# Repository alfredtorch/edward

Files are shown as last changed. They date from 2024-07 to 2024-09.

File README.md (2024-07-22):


Edward is an innovative solution that synergizes citizen science with urban farming, utilizing an advanced aquaponic system to address environmental challenges. Edward aims to produce sustainable food sources while fostering community involvement and contributing to a healthier, more sustainable urban environment.

Designed as an expansive urban farming laboratory, Edward initially focuses on aquaponics. This highly efficient farming method is capable of producing local food with minimal resource impact and effort. By transforming existing water bodies, such as ponds or basins, into productive food sources, Edward epitomizes the principles of the circular economy.

Key Features
- Smart Garden Community: Build your self-sufficient technology platform and transform public spaces into urban farming areas.
- Citizen Science: Share information and engage in community-driven research.
- Open Source: Driven by the community, promoting collaboration and innovation.
- Modular Design: Based on the principles of the circular economy, allowing adaptability and scalability.
<p align="center">

</p>

> ## Software Development Needed
> Please visit the [Software Specification Sheet](SoftwareSpecificationSheetM2.md) if you would like to collaborate and help to develop Edward.
> ## On-Going Documentation
> Different sections in this repository needs to verified. Please feel free to submit corrections, if you would like to collaborate and help to develop Edward.

# Growing Lab & Sharing Knowledge
Edward fosters continuous improvement through community involvement at multiple levels. Individuals manage local stations, benefit from fresh food, and participate in testing new biological scenarios. This approach enriches community knowledge and enhances the numerical model.

<p align="center">

</p>

The Sustainable Food Cycle and Optimization Biological Cycle are central to Edward's innovative approach. The Sustainable Food Cycle focuses on creating a cradle-to-cradle system where organic waste is transformed into bio converters and natural bio cycles, producing organic food for fish and yielding fresh vegetables. This cycle epitomizes resource efficiency and sustainability. Meanwhile, the Optimization Biological Cycle leverages citizen science and advanced technologies like machine learning and autonomous control to refine and enhance farming practices. Through community-driven research, scenario experimentation, and gamification, this cycle ensures continuous improvement and optimization of the entire system.

<p align="center">

</p>

## Sharing Knowledge
For individuals, Edward offers a novel way to connect with nature and their community. Members assume shared responsibility for their plants and fish, gaining knowledge and forming new connections, both digitally and in person. This hands-on experience not only yields healthy food but also underlines a Return on Research (RoR) approach, valuing the knowledge gained from community-led research and innovation.

Key Features
* Citizen-Operated Stations: Gather observations for new biological scenarios like light conditions or tidal cycles.
* Mobile App Support: Easy sharing of observations with scientists, encouraging dynamic information exchange.
* Participative and Gamified Approach: Encourages dialogue, sharing through text and images, and collective data contribution.
* AI-Driven Insights: Data from multiple stations feed into AI models for valuable insights into small-scale and industrial agricultural practices, such as pisciculture.

## Research Project 1 : Water Cooled LEDs


Improve the maintenance cost and efficiency with water-cooled LEDs for grow lights. This study focuses on the efficient thermal management of the grow light. Optimal cooling will provide long-term stable light characteristics and increase lifespan. Additionally, the possible waste heat can be used to heat the fish tank.

## Phases
1. **Design Possibilities:** Explore various design possibilities such as heat sinks, LED holders, and more.
2. **Check Safety Concerns:** Address safety concerns including risks of electrocution, fire hazards, and appropriate light levels.
3. **Regulate Water Pump and Light Intensity:** Control the water pump and adjust light intensity based on a state machine and scheduling.
4. **Measure Light Quality:** Assess light quality by measuring energy, wavelengths, and consumption over time.

## Development Project 1 : Move away from Home Assistant


The current prototype system is powered by Home Assistant with ESPHome running on a local Raspberry Pi. This setup was great for quickly prototyping a proof of concept. However, the main challenges faced by the current system are:
- It is not a standalone system (requires both Raspberry Pi and Station Controller).
- There is no option for easy remote monitoring of the system (NAT, DNS, Public IP).
- Missing control options (regular self-calibration, failsafe mode).

<p align="center>
  >
</p>

# Files & Folders
The project is currently mainly organised in this respository.
All shared by Licence... 
## [Hardware](Hardware.md)
## [Hardware PCB Repo](/Hardware/)
## [Components](Components.md)
## [Software YAML Repo](/Software/)
## [Software Devlopement Specification Sheet](SoftwareSpecificationSheetM2.md)
## [Discord Server](https://discord.gg/AFunXj2wjE)
## [HackADay.io Project](https://hackaday.io/project/197025-edwardfarm)

<a href="https://trackgit.com">
trackgit-views
</a>

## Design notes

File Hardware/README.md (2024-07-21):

| Filename | Notes |
| --- | --- |
FishTankControllerV2 | Control the Greenhouse & Fish Tank with safe DC motors |
GreenHouseControllerV2 | Control the Greenhouse & Fish Tank with with powerful AC motors |
IoTSSensorBoardV2 | Measure Heatsink Temperature LM75B or TMP1075 |
PowerMosfetGSVINRailV1 | Control 4 DC Load Module with GreenHouseControllerV2 |
PowerMosfetsSGVINRailV1 | Control 4 DC Load Modulel Module with GreenHouseControllerV2 |
Relay4ChannelBoard | Control 230V Relay 4Channel Module with GreenHouseControllerV2 |
SSR4ChannelBoard | Control 230V SSR 4Channel Module with GreenHouseControllerV2 |

<p align="center">

<br>
8 Channel Rebel - 8ChannelRebelSSR_v5
<br>

<br>
Helios - 8ChannelIoTLEDDriver
<br>

<br>
Green House - GreenHouseControllerV2
<br>

<br>
FishTankControllerV2
<br>

<br>
Relay4ChannelBoard - Control 230V Relay 4Channel Module with Green-House
<br>

<br>
SSR4ChannelBoard - Control 230V SSR 4Channel Module with Green-House
<br>

<br>
PowerMosfetGSVINRailV1
<br>

PowerMosfetSGVINRailV1
<br>
</p>

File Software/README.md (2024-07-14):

| File Name | YAML Content or Notes |
|---|---|
| Edward ESPHome.yaml | |
| Edward Helios ESPHome.yaml | Prototype Script for LED Grow Light (DC) with Temperature Monitoring |
| Edward Terra ESPHome.yaml | Prototype Script for Aquaponics with Tide and Light Scheduler (Optical Switch) |
| Edward User Interface.json | Node-Red Dashboard based on SVG UI Design |
| edward-grow-fuel.yam | Prototype Script for Aquaponics with Tide and Light Scheduler (Fuel Gauge) |

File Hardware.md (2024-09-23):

# Green House - Terra
The Green House - Terra board is designed to seamlessly integrate with your agricultural setup, enabling precise control over various actuators to enhance food production. This versatile board supports multiple devices and actuators, such as pumps and lights, making it ideal for diverse applications. While the fishtank version is highly accessible and beginner-friendly, the Green House - Terra platform offers unmatched versatility, capable of switching heavy loads running on mains power.

Features:
* ESP32-based
* Tasmota and Esphome Compatible
* Many PIN configuration possible (Solder Jumper)
* Many Vcc Configuration possible (Solder Jumper) with On Board Power Regulator 
* Open Source

<p align="center">

</p>

## Components
| Component | Description | Component | Description |
|---|---|---|---|
| ESP32 MCU | The core microcontroller unit powering the board | QWIIC I2C Connector | Simplifies the connection of sensors and modules |
| 4 Inputs for Water Level (Optical)  | Monitors water levels to ensure optimal conditions | Flow Meter (Hall Sensor) | Measures water flow rate accurately |
| Thermistor (Analog Temperature) | Provides precise temperature readings | 1-Wire Digital Temperature Sensor | Enables digital temperature monitoring |
| Sonar Sensor (Distance) | Measures distance using sonar technology | 4 Solid State Relays (5V Level) | Controls high-power devices with reliability and safety |
| Fan (Speed Control, Tachometer Sense) | Manages airflow with speed control and tachometer feedback | 2 Power Outputs (PWM-DC) | Drives power-hungry devices with PWM control |
| LED Strips (5V Data Line) | Controls LED lighting for various applications | Stepper Motor (28BYJ-48) | Drives stepper motors for precise mechanical control |
| 2 GPIO Pins | General-purpose input/output pins for custom applications | 2 Limit Switches | Detects end positions or limits in mechanical movements |
| Air Sensor (Humidity, CO2, Temperature, Pressure) | Monitors air quality and environmental conditions | Multiple VCC Buses | Provides flexible power distribution across multiple components |

## Pin-Out

| Pin  | Option 1 | Option 2 | Note |
|---|---|---|---|
| IO0  | Fan Signal Tacho | Stepper C | GPIO Selector Solder Jumper |
| IO2  | LED Status | | |
| IO4  | RGB | Solder Jumper | |
| IO5  | PIO3 | 5V Level - Mosfet Output | |
| IO12 | Button Board  | | |
| IO13 | PIO4 | RGB Pixel | 5V Level - Load Output |
| IO14 | Limit 1 | Servo 1 / Sonar Trigger | GPIO Selector Solder Jumper |
| IO15 | Servo 2 | Stepper D | GPIO Selector Solder Jumper |
| IO16 | Fan PWM | | |
| IO17 | 1-Wire | Dallas 1 Wire Sensor | |
| IO18 | Turbine Tacho | Flow Meter | |
| IO19 | PIO1 | | 3V3 Level |
| IO21 | SDA | | 3V3 Level |
| IO22 | SCL | | 3V3 Level |
| IO23 | PIO2 | | 5V Level |
| IO25 | Limit 1 | Stepper B | GPIO Selector Solder Jumper |
| IO26 | Turbine Therm | Water Temperature | |
| IO27 | Servo 1 / Sonar Trigger | Stepper A | GPIO Selector Solder Jumper |
| IO32 | Fan Tacho | Limit 2 | GPIO Selector Solder Jumper |
| IO33 | Limit 2 | Servo 2 | GPIO Selector Solder Jumper |
| IO34 | Water LEVEL 3 | | Optical or physical switch  |
| IO35 | Water LEVEL 2 | | Optical or physical switch  |
| IO36 | Water LEVEL 4 | Sonar Echo | Optical or physical switch  |
| IO39 | Water LEVEL 1 | | Optical or physical switch  |
| VIN1 | USB C, STEPPER, SERVO | | Max 30V, Input of DCDC 5V & 3V3 - direct 5V |
| VIN2 | RGB, VFAN, MOSFET | | Direct 5V |
| 5V | RGB, STEPPER, SERVO, MOSFET, VFAN | | |
| 3V3  | SERVO, MCU | | |

_Note: If a component (e.g., a Servo) operates at different voltage levels, it can be configured to use a single power source (e.g., 5V) through the use of solder jumpers._

<p align="center">

</p>

## ToDo
- [x] Use as Aquaponics Controll with ESPHOME (both fuelgauge and optical water)
- [ ] Test all configurations 

## Version

| Model | Notes |
|---|---|
| FishTankController V1  | Flow Meter Issue, 4 On-Board Load Power Switches (DC, Avoids 230V)  |
| GreenHouse V1 | Flow Meter Issue, 4 External Power Controls (AC & DC), Sonar |
| Fishtank | Integrate Library for Counter, 4 On-Board MOSFETs |

<p align="center">

<br>
A working Green-House Controller running the cycle of our first station.
</p>

# Helios
This design allows you to tweak all the different light levels your plant deserves, while keeping everything cold. It uses a third-party LED circuit but allows you to build your own.
Features:
* ESP8266-based
* Pluggable LED Drivers 8 Channel + 1 external PWM 
* Tasmota and Esphome Compatible
* Open Source
* On Board Power Regulator
* Water Cooling Control and Sense (Flow and Temperature Meter)
* On-Board LEDs helps to notifity about the system health

<p align="center">

</p>

## Components

| Component | Description | Component | Description |
|---|---|---|---|
| ADC121C021 | ADC for Turbine Temperature NTC | EMC2101 | Fan Controller & Tach Monitor |
| DS1683S | Event Counter for Water Flowmeter | PCA9685 | PWM LED and Power Switch |
| PCA9685 | PWM LED and Power Switch | LTC4311_SC70 | Improving I2C Stability (not populated) |
| TMP1075DGKR5  | On Board Temperature Sensor | VNN7NV04PTR-E | Smart Switch 4 Channel like  max 30V at 6A (Low Side) |
| PT4115 | LED Driver IC Module | ESP-01 | MCU present in ESP8266 and ESP32 |

_Note: I2C device addresses are selectable with solder jumpers._

## Pinout 

| Pin | Controls | Pin | Controls | Pin | Controls | Pin | Controls |
|---|---|---|---|---|---|---|---|
| PWM0  | M4 Load | PWM6  | LED 6 | PWM12 | Servo | IO0 | SDA from MCU |
| PWM1  | M3 Load | PWM7  | LED 5 | PWM13 | Error LED | IO2 | SCL from MCU |
| PWM2  | M2 Load | PWM8  | LED 1 | PWM14 | Status LED | RST | Reset Button MCU |
| PWM3  | M1 Load | PWM9  | LED 2 | PWM15 | Fan PWM | | |
| PWM4  | LED 11 | PWM10 | LED 3 | WTemp LED| ADC121 Alarm | | |
| PWM5  | LED 7 | PWM11 | LED 4 | WTach LED| DS1683S Alert| | |

_Note: If an EMC2101 is mounted, J15 should not be connected to isolate PWM15 and prevent interference._

## ToDo
- [X] 9 Channel, On-Board  + Alu Heat Sink Temperature, controlled by ESPHOM
- [ ] EMC2101 test
- [ ] Integrate DS1683S in ESPHOME
- [ ] Try DS1682 for Event Counter
- [ ] Write an advanced code (GUI - Scheduler for it)

<p align="center">

<br>
A working Helios setup emitting around 150 Watt of light output, water and air cooled. Mounted on a eurobox.
</p>

# 8 SSR Rebel Channel
This design allows you to control and dim your AC appliances. For a grow tank, this can be light output, and for an irrigation control valve. Applying phase dimming to an unsupported appliance may destroy it. Careful checking and handling are required while using the device.

This system provides all the different light levels your plant deserves while keeping everything cool. It uses a third-party LED circuit but allows you to build your own.

Features:
- **ESP32-based:** Built around the reliable and efficient ESP32 microcontroller.
- **Tasmota and ESPHome Compatible:** Easily integrates with popular home automation frameworks.
- **8 Channel Phase Dimming of AC Loads (0-100%):** Equipped with a dedicated Schmitt-Trigger for stable operations.
- **On-Board ACDC Power Supply:** Ensures stable power management.
- **AC Current Monitor:** Monitors the current to ensure safe and efficient operation.
- **GUI with Display and Encoder:** User-friendly interface for easy control and monitoring.

<p align="center">

</p>

## Components
| Component | Description | Component | Description |
|---|---|---|---|
| AQG22212 or G3MB-202PL | SSR AC 2Amp No Zero Crossing | Rotary Encoder | Fan Controller & Tach Monitor |
| WS29812 | Event Counter for Water Flowmeter | OLED | PWM LED and Power Switch |
| Jack 3,5mm Current | Circuit for reading SCT-013 | IR Receiver | Receives commands from IR Remote Control |
| DS18b20 | On-board or JST Plug for temperature reading | Button & Potentiometer | User Interface and analog read |

## Pinout
| Pin | Controls | Pin | Controls | Pin | Controls |
|---|---|---|---| ---|---|
|  IO26 | SSR1 | IO39 | Analog | IO22 | SCL |
| IO18 | SSR2 | IO35 | InfraRed | IO25 | SDA |
| IO19 | SSR3 | PWM9 | ZeroCrossing | IO13 | EncoderA |
| IO23 | SSR4 | IO33 | CurrentSignal | IO36 | EncoderB |
| IO17 | SSR5 | IO02 | Temp | IO4 | EncoderS |
| IO16 | SSR6 | IO32 | RGB | | |
| IO27 | SSR7 | PWM13 | BTN | | |
| IO25 | SSR8 | | | | |

_Note: Zero Crossing = can be used as main detector (binary state) JP2 connected or zero crossing phase detector (periodic trigger) JP2 blank)._
<p align="center">

<br>
A working SSR 8 Rebel Controller controlling 6 LED Channel, 1 Waterpump and 1 Fan.
</p>

## ToDo
- [X] 8 Channel AC Phase Dimmed controlled by ESPHOME
- [ ] Current Clamp Monitor Not yet tested
- [ ] GUI components not yet tested

# Green House Micro
This design allows you to control and dim your AC appliances. For a grow tank, this can be light output, and for an irrigation control valve. Applying phase dimming to an unsupported appliance may destroy it. Careful checking and handling are required while using the device.

This system provides all the different light levels your plant deserves while keeping everything cool. It uses a third-party LED circuit but allows you to build your own.

Features (To be upadte)
- **ESP32-based:** Built around the reliable and efficient ESP32 microcontroller.
- **Tasmota and ESPHome Compatible:** Easily integrates with popular home automation frameworks.
- **8 Channel Phase Dimming of AC Loads (0-100%):** Equipped with a dedicated Schmitt-Trigger for stable operations.
- **On-Board ACDC Power Supply:** Ensures stable power management.
- **AC Current Monitor:** Monitors the current to ensure safe and efficient operation.
- **GUI with Display and Encoder:** User-friendly interface for easy control and monitoring.

<p align="center">

</p>

## Components
| Component | Description | Component | Description |
|---|---|---|---|
| AQG22212 or G3MB-202PL | SSR AC 2Amp No Zero Crossing | Rotary Encoder | Fan Controller & Tach Monitor |

## Pinout
| Pin | Controls | Pin | Controls | Pin | Controls |
|---|---|---|---| ---|---|
|  IO26 | SSR1 | IO39 | Analog | IO22 | SCL |
| IO18 | SSR2 | IO35 | InfraRed | IO25 | SDA |
| IO19 | SSR3 | PWM9 | ZeroCrossing | IO13 | EncoderA |
| IO23 | SSR4 | IO33 | CurrentSignal | IO36 | EncoderB |
| IO17 | SSR5 | IO02 | Temp | IO4 | EncoderS |
| IO16 | SSR6 | IO32 | RGB | | |
| IO27 | SSR7 | PWM13 | BTN | | |
| IO25 | SSR8 | | | | |

_Note: Zero Crossing = can be used as main detector (binary state) JP2 connected or zero crossing phase detector (periodic trigger) JP2 blank)._
<p align="center">

<br>
A working SSR 8 Rebel Controller controlling 6 LED Channel, 1 Waterpump and 1 Fan.
</p>

## ToDo
- [X] Fix AC Switch PO-SSR Mix Up ULN2008 
- [X] Fix Labeling - Wrong Pinout
- [X] Figure Out Buzzer (3v)
- [X] Fix Documentation (Copy Paste)
- [X] Remove Presence need for mmWave Sensor
- [X] Add Mechanical Button below Capaciv
- [X] Remove ACDC Main LED
- [X] Think about IC GPIO Foot Print
- [X] ADD Edward Logo to it
- [X] Check for Wifi Limitation during ADC GPIO
- [X] Check resistor for dallas - Remove multiple Pin attribuation on esp32

# [Components](Components.md)
One design goal is to easily integrate new components without needing to revert to a breadboard design. These components should mainly be COTS (Custom-Off-The-Shelf) goods for easy and cost-efficient sourcing. A detailed overview is provided. These integrations can result in direct on-board implementation or require additional PCB designs available in the [available in the Hardware Repository](/Hardware/).

<p align="center">

</p>

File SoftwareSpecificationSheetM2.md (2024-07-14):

# Milestone 2

## Current Prototype

### System Overview
The current prototype operates on an Ebb and Flow (Media-based) Aquaponics system, which requires a tidal mechanism to periodically raise and lower the water level. This process is crucial for oxygenating the roots and facilitating the filtration of nutrients in the plant tank.

<p align="center">

</p>

The current prototype system is powered by Home Assistant with ESPHome running on a local Raspberry Pi . The main challenges faced by the current system include:
*	not a standalone system (Raspberrypi + Station Controller)
*	no option for easy remote monitoring of the system (NAT, DNS)
*	missing control options (regular self-calibration, failsafe mode)

<p align="center">

</p>

### System Components

The current prototype remains on the following setup.
| Category | Component | Description | Type |
|---|---|---|---|
| **Plant Tank** | 1x Falling Tide Pump | Pumps from plants to fish | SSR 220V - PIO |
| | 1x Water Level Top (PTT)  | Sense if the max. volume is reached | Replaced by Fuel Gauge Sensor |
| | 1x Water Level Bottom (PTB) | Sense if the max. volume is reached | Replaced by Fuel Gauge Sensor |
| | 1x Growing LED (optional) | Basic AC Control, no dimming | SSR 220V - PIO |
| | 1x Water Temperature Sensor | Measure water temperature | 1-Wire: DS18B20 |
| **Fish Tank**  | 1x Rising Tide Pump | Pumps from fish to plant | SSR 220V - PIO |
| | 1x Flow Meter (optional) | Turbine based | Interrupt PCTN² |
| | 1x Aquarium Heater (optional) | Heat the water | SSR 220V - PIO |
| | 1x Air Pump | | 220V - NC/Always ON |
| **Accessory** | 1x Gas sensor (Optional) | For Air Monitoring | BME680 |
| | 1x OLED Display (Optional) | For User Interface | |
| | 2x Buttons (Optional) | For User Interface | |

<p align="center">

</p>

## Embedded Software Development
<p align="center">

</p>

The core goals of this software development phase are:

* Create the Edward Controller, which is responsible for maintaining optimal conditions conducive to the health of aquatic life and plant growth.
* Design a User Interface that assists users in configuring their stations and managing basic settings with ease.
* Facilitate remote connectivity through the IoT Integrator, enabling access and control over the internet.
* Design a digital twin for virtual testing the system – Testing on a real station.

### Cycle Control
The Edward Controller's main function is to oversee the plant tank's automated tidal process. The software is engineered for reliability, crafted to maintain functionality in the face of technical challenges such as power outages and sensor errors. Operational scenarios are meticulously detailed within a truth table and in the analysis of Worst-Case Scenarios.

<p align="center">

</p>

### System  Considerations
 __Syphon__
 
Due to the falling pump's elevated position above the fish tank's outlet, a natural
siphon effect occurs, which allows the circuit to continue draining even when the
pump is not powered. This siphon effect could present a problem if it coincides with
the pump's rising cycle, as it would exacerbate the drainage and potentially trap the
system in a continuous loop and cause timeout errors. To mitigate this, the duration
of the low tide must be sufficiently long to ensure that the siphoning ceases before
the next cycle begins. The necessary duration of this delay is variable, as the
duration of the siphon effect is dependent on the height difference between the
bottom water level sensor and the drainage pump exit.

__Input Processing__

The inputs received from the water level sensors require filtering and debouncing. This approach is designed to stabilize the readings and avoid false triggers that could result from wavegenerated
perturbations.

__Plants Illumination__

The system's lighting is managed by a straightforward scheduling mechanism,
which automates the grow lights, toggling them on and off as programmed.
Although the current iteration lacks the functionality to adjust light intensity, the
timing of the grow light is synchronized with the natural patterns of sunrise and
sunset. This synchronization provides the essential dark periods that plants require
for their rest and recovery during the nigh.

__Safety Mechansim__

| Situation | Result | Severity | Worst-Case Scenario Prevention |
|---|---|---|---|
| Total drainage of the fish tank | Dead fish | High | Position rising pump above the min. water level. Limit operation time of the rising pump. |
| Tank Overflow | Flooding the environment | High  | Install an overspill safeguard in the plant tank. Ensure fish tank capacity equals total water supplied. |
| Not synced time | Stressed plants due to excessive light | High | Synchronize system clock accurately (consider location-based settings). |
| Dryness in the plant tank | Stressed and dry plants | Medium | System can endure temporary dryness. |
| Power Failure | Fish suffocation | High | Implement a heartbeat signal for regular checks. Automate system reboot when cycling stops. |
| Internet Failure | No remote control and telemetry | Low  | Queue commands until connectivity is restored. Have a secondary access point as a fallback. |
| Pump Failure | Nutrient imbalance | Middle | System can tolerate short-term pump failure. |
| Hacker Attack | Compromised system | High | Hardcoded vital function. Enable safety mechanisms to prevent unauthorized use. |
| Overheat | Dead Fish | High | 2 layers of safety (Edward control & Thermostat). |

__Flow Meter (Optional)__

The integrated flow meter is essential for providing precise volume measurements
during the rising tide phase. It accurately gauges the total water capacity of the plant
tank. As plant roots grow and biomass increases, a natural reduction in the apparent
water capacity of the tank is expected. Therefore, a decrease in measured volume
over time can be indicative of healthy plant growth.
For routine monitoring, the flow meter serves as a diagnostic tool, offering
straightforward feedback—either confirming successful tank filling (OK) or detecting
issues (NOK). This feedback is crucial as it works with the water level sensors,
providing a secondary verification method to ensure that water-related sensors are
functioning properly.

__Water Heater (Optional)__

Aquarium heaters are typically equipped with built-in thermal controls, so no
special operations are required for this setup beyond the ability to turn the heater
on or off. For optimal functionality, it is crucial that the heater's operational state
persists through a power outage.
The water heater should operate within a defined temperature range for safety and
efficiency. If the water temperature falls below the minimum threshold, indicating
that the heater may not be functioning properly, the user should receive a
notification. Conversely, if the temperature exceeds the maximum limit, suggesting
excessive heating, the system should automatically turn off the heater and alert the
user to this condition.

### Tidal State Machine
During the current development phase, the system has been designed to manage
tidal controls through four distinct operational modes:
1. Calibration: Adjusts and sets the baseline parameters for tidal operations.
Normally occurs on first start and on demand.
2. Automatic Tidal: Executes water level adjustments based on predefined
settings without user intervention.
3. Manual: Allows users to directly control tidal settings for maintenance.
4. Faulty: Stops the related process (tidal or heating) as a safety measure.

<p align="center">

</p>

The diagram illustrates the transitions between modes, which are governed by
three types of triggers:
1. Time-Out Based: The system automatically shifts modes after a certain time
without receiving commands or if a process takes too long.
2. User Command: The user manually initiates a mode change.
3. Process Control: The system's internal processes dictate the shift from one
mode to another, typically for calibration or error handling.
The transitions detailed in the state machine, with their respective triggers, are
designed to be flexible. The primary objective is to establish safety measures
through restrictions that govern the switch from one operating phase to another.

### Calibration Mode
This mode measures the total water displacement (Vinitial). It is a critical process that
allows for the assessment of water movement and ensures that all system
components are functioning correctly. During this process, time out values are
obtained for the later automatic monitoring:
* Rising time = Bottom-Middle + Middle-Top
* Falling time = Top-Middle + Middle-Bottom
If in any case a pumping operation reaches the timer of maximum duration (hardcoded),
the system will trigger a faulty system.
During rising tide, the flow meter can calculate the total water displacement.

<p align="center">

</p>

__User Defined Tidal Height (Optional)__

This development objective ensures that the water displacement during a rising tide
is adjustable. Consequently, the limit of the TOP state is no longer bound by the
level sensor but is instead determined by the adjusted rising time or by using a flow
meter. Due to the siphon effect, the BOTTOM level cannot be adjusted since it will
always drain to the lowest point. Implementing this feature for automatic tidal
requires more complex scheduling and will remain functional as long as the plant
level sensors stay in the same position. If the sensors are moved, a complete
calibration cycle will be necessary.

__Automatic Tide Cycle__

This elementary process loops in an endless cycle of high and low tides in the plant
tank. Users can define the settings of the tide (High-Low Tide Duration & User-
Defined Tidal Height).
Doing so, the duration of a complete tide cycle is defined by:
" Total Tide Duration = Rising Time + Duration High Tide + Falling Time +

Duration Low Tide
In terms of state system and monitoring, the following truth table provides a
comprehensive overview:

| PTB | PTT | Level  | Direction | Next State | Action/Comment | Issue |
|-----|-----|---|---|---|---|---|
| 0 | 0 | Bottom | Rising | MIDDLE | Pump & Timer Control | 0 |
| | | | Falling | WAIT→MIDDLE | Tide done (Wait) | 0 |
| 0 | 1 | DC | DC | DC | Check Sensor Water | 1 |
| 1 | 0 | Middle | Rising | TOP | Pump & Timer Control | 0 |
| | | | Falling | BOTTOM | Pump & Timer Control | 0 |
| 1 | 1 | Top | Rising | WAIT→MIDDLE | Tide done (Wait) | 0 |
| | | | Falling | MIDDLE | Pump & Timer Control | 0 |

DC : Don’t care - ISSUE: 2 – no operation (faulty) / 1 – critical sensor situation (automatic) / 0 – no
restriction (automatic)

__External perturbation__

This occurs when a state change in the water level sensors (PTB,PTT) during a no-pumping phase. This abnormal sensor behavior (indicating a fault) can also result from an unexpected water loss or gain of the plant tank.

A faulty sensor should be detected during the rising phase by checking the flow
meter and timer’s benchmarks. Even when the sensors are not functioning (critical
sensor situation), if previously calibrated accurately, it can continue to operate using
the flow meter for the rising tide and a pre-set timer for the falling tide. 

To utilize the siphon effect, a long low tide timer is employed. This issue should be resolved once
maintenance occurs, with a complete calibration cycle required to reset the system.
This situation should be addressed swiftly as the absence of overfill protection and
the potential for the pump to run dry could compromise system integrity. Therefore,
the user should be notified about the reduced safety mechanism.

Error management is further supported by timeout counters for different operational phases. Transition durations are critically evaluated against two types
of limits:
* Variable values derived from calibration cycle mode.
* Hard-coded values serve as an additional layer of security (especially during
calibration and manual operation).

Should either set of limits be reached, the system is programmed to either transition
into a faulty state or operate with reduced functionality, alerting to a critical sensor
situation:

| Direction | Level | Transition | Flow Meter | Issue |
|---|---|---|---|---|
| Rising | Bottom  | Bottom→Middle  | OK | Faulty PTB Sensor (or water-leak) → 1 |
| | | | NOK | Faulty rising pump or not enough water → 2 |
| Rising | Middle  | Middle→Top | OK | Faulty PTT Sensor (or water leak) → 1 |
| | | | NOK | Faulty rising pump or not enough water → 2 |
| Falling | Top | Top→Middle | DC | Wait if Top→Bottom (only PTT faulty) → 1 |
| | | | | else (Faulty falling pump, clogged circuit) → 2 |
| Falling | Middle  | Middle→Bottom  | DC | If Top→Middle before (only PTB faulty) → 1 |
| | | | | else (risk of overfill at next rising) → 2 |

DC : Don’t care - ISSUE: 2 – no operation (faulty) / 1 – critical sensor situation (automatic) / 0 – no
restriction (automatic)

__Manual Mode__

In Manual Mode, users are granted direct control over the pumps through both the
User Interface and remote access. However, this mode does not allow the user to
bypass any of the safety features established in the Automatic Tidal Mode.

| Control | Description |
|---|---|
| Fill Plant Tank | Fills the plant tank to capacity and maintains the water level. |
| Drain Plant Tank  | Empties the plant tank completely and maintains this state. |
| Pause Cycle | Halts all pumping actions, preserving the current water level. |
| Fast Cycle | Turn rising-falling pump on. |
| Force Calibration | Execute a complete calibration cycle (→ automatic tidal) |
| Switch Light | Toggles the current state of the grow light on or off. |
| Switch Heater | Toggles the current state of the aquarium heater on or off. |

The return to Automatic Tidal Mode should be triggered based on time-out or user
interaction. At that moment, the system should remember it water's level state to
properly restart.

__Faulty Mode__

Faulty Mode is activated exclusively in response to a critical system issue that
typically requires manual intervention for resolution. This may involve tasks such as
repairing a sensor or readjusting water levels. When in Faulty Mode, the system
enters an Overwrite state, where only pumping commands are accessible through
the local GUI.

To ensure the system exits Faulty Mode correctly, specific procedures must be
followed. These procedures typically involve verifying the resolution of the issue,
calibration parameters and reestablishing normal operational mode.

__Monitoring Values__

**State Machine**

| Mode | Actions and Options |
|---|---|
| Manual Mode: | Fill Plant Tank - Drain Plant Tank - Pause Cycle - Fast Cycle - Force Calibration - Switch Light - Switch Heater |
| State Machine| Calibration - Automatic Manual - Faulty |
| Issue | 0 OK - 1 Critical - 2 Faulty |
| Latest Log Entry | Time & Date Action (e.g., "22.12.23 7h04 Rising Tide...") |

**Duration**

| Category | Specification | Notes |
|---|---|-----|
| Station ID - Name | Generate ID (from chip) and set name for identification | |
| Version | Firmware Version | |
| Time | Hours and Minutes and Sunset-Sunrise / No Set | |
| High Tide Duration | By User in Minutes (limit by Max. High Tide Duration) | |
| Low Tide Duration | By User in Minutes (limit by Max. Low Tide Duration) | |
| Critical Tide Duration| Equals Max. Low Tide Duration (for max. siphon effect during issue) | |
| Bottom→Middle | By measuring[^1] (limit by Max. Bottom-Middle Duration) in Seconds| |
| Middle→Top | By measuring[^1] (limit by Max. Middle-Top Duration) in Seconds | |
| Top→Middle | By measuring[^1] (limit by Max. Top-Middle Duration) in Seconds | |
| Middle→Bottom | By measuring[^1] (limit by Max. Middle-Bottom Duration) in Seconds| |
| Manual→Automatic Mode| By User in Minutes (limit by Max. Manual Mode Duration) | |
| Growing Lights | By User in Minutes (limit by Max. Light per 24h) | Optional |
| Usage pump, lights | By counting operating hours counter (Reset per device GUI) | |

[^1]: Calibration or continuously

**System Related**

| Name | Units |
|---|---|
| Capacity Plant Tank | Liters measured by the flow meter during calibration |
| Current Volume | Liters estimated based on time (falling tide) or rising tide (flow meter) |
| Level Direction | Bottom-Middle-Top |
| Water Temperature | Heating switch on off based on min and max temperature range |
| Heater Pump Output  | Falling ON OFF Rising ON OFF |
| Digital State Input | PTB ON OFF / PTT ON OFF / Flow Meter |
| Tidal Height | If user-defined height in % or Liters (not mandatory) |
| Flow Meter | OK (>1/minute) - NOK |
| Ambient Air Quality | Readings from BME680 (°H, %C, kPa-CO2) |

While the current focus is on establishing core functionalities, more advanced monitoring capabilities, such as pH level tracking and the option to export data in CSV format, are planned for a later phase of development. These features will primarily be cloud-based to leverage enhanced data processing and storage capabilities.

However, if integrating historical temperature data proves straightforward, this enhancement could be included in the current development phase. The aim would be to provide users with daily and monthly views of temperature data etc., including minimum and maximum values recorded over these periods. This feature would enhance user experience and provide valuable insights into the system's performance for predictive maintenance.

## Local Gui
This interface will be designed as a web page hosted on a local web server, functioning independently without requiring external internet connectivity. This design choice allows users to conveniently update and configure various hardware components of the system, such as pumps and sensors.

If a faulty state occurs, the user can override the timers and sensors and operate the machine without any safety mechanism.

The control functionalities provided will be consistent with those described in the Tidal Control's Manual Mode. Additionally, the interface will facilitate basic operations, including time synchronization. The attached images serve as preliminary sketches, providing an initial visual concept of what the interface might look like and how it might operate.

<p align="center">

<br>

</p>

## Wifi Connectivity
On first startup, a local access point for Wi-Fi connection should be provided. Doing
so, the user sets up necessary settings through a web page interface. Therefore, this
user interface should be always available regardless of the current state.

## IoT Integrator
For remote access capabilities, the system is designed to support data exchange
and basic control operations/settings through a potential platform like
Thingsboard. This choice enables efficient device management, data collection,
processing, and visualization, facilitating integration while also aiming to reduce
costs.

Key features will include data telemetry and the possibility of implementing Over-
The-Air (OTA) updates to ensure the system remains up-to-date and secure. All
connections will be safeguarded to protect user data from unauthorized access.
The remote interface will offer the same command capabilities as found in Manual
Mode. Additionally, crucial parameters, such as tide definitions, will be configurable
through this interface, providing administrators with comprehensive remote control
over their different stations. In a later development phase, this data should be
integrated in a user-friendly application providing maintenance reminders and
push notifications.

## Development Organisation
"This specification document not only outlines technical propositions but also remains open to alternative approaches in development. To ensure efficiency and maintainability, the programming strategy should incorporate the following principles:
* Avoiding large blocks of nested if-else statements in favor of concise and effective routines.
* Adopting a C++ programming approach to benefit from structured and object-oriented programming, which encourages the creation of reusable and modular code.
* Ensuring robustness and scalability to support future enhancements, such as intensity management for grow lights and the inclusion of additional control options.
*  Structuring the development into divided milestones to reduce complexity."
As mentioned earlier, specific functionalities and variables, including pinouts and
duration settings, may be hard-coded during this phase of development for
simplicity and efficiency. Concerning the state machine and various critical levels,
there is a potential for errors. We welcome any corrections or suggestions for
improvement in these areas.
Flexibility for improvement and adaptation of the described processes is crucial.
For programming inspiration, a list of potential libraries is attached to this
document.
For testing, a working prototype can be made available, or a remote laboratory
setup with a webcam can be used. However, a more modern approach might
involve implementing a digital twin. This would allow for thorough testing of all
different states and scenarios without the complications of physical hardware.

## Licence

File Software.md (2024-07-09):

# Software
## Current State
3# Use-Case - App Store




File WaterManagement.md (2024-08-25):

# Measurement

## Water Analyser

| Test (DE/EN) | Already Ordered | To Be Purchased Separately | Importance | Recommended Value | Description |
|---|---|---|---|---|---|
| Freies Chlor / Free Chlorine (DPD1) | Yes | - | High | 0-0.5 mg/L | Important for assessing disinfection performance. |
| Gesamtchlor / Total Chlorine (DPD3) | Yes | - | High | 0-0.5 mg/L | Important for overall assessment of chlorine levels. |
| pH-Wert / pH Level | Yes | - | High | 6.5-7.5 | Measures the acid/base level of the water. |
| Cyanursäure / Cyanuric Acid (CYA) | Yes | - | Medium | Control range | Stabilizes chlorine against UV degradation. |
| Alkalinität / Alkalinity (AlkalM) | Yes | - | High | 80-120 mg/L | Buffer capacity of the water, important for pH stability. |
| Ammonium / Ammonium | - | Yes | Very High  | 0-1 mg/L | Ammonia from fish waste; toxic, should be minimized. |
| Chloramine / Chloramines | - | Yes | High | 0-0.2 mg/L | Harmful to fish, needs to be controlled. |
| Eisen LR / Iron LR (Low Range) | - | Yes | Medium | 0-0.3 mg/L | Iron levels, important for plant health. |
| Nitrat / Nitrate | - | Yes | High | 5-10 mg/L | Nitrogen source, important for plants. |
| Phosphat LR / Phosphate (Low Range) | - | Yes | Medium | 0-1 mg/L | Phosphorus source, to be controlled to prevent algae growth. |
| Kalium / Potassium | - | Yes | High | 5-10 mg/L | Important for plant growth. |
| Gesamthärte / Total Hardness | - | Yes | Medium | 120-180 mg/L | Water hardness, important for fish health. |
| Kalziumhärte / Calcium Hardness | - | Yes | High | 120-180 mg/L | Calcium content, important for both plants and fish. |
| Kupfer / Copper | - | Yes | Medium | 0-0.2 mg/L | Harmful in high concentrations, monitor copper levels. |
| Sulfat / Sulfate | - | Yes | Medium | 80-120 mg/L | Sulfur content, important for proteins. |

| Factor | Influence on pH | Direction |
|---|---|---|
| **Temperature** | Rising temperatures increase biological activity | Lowering |
| **Biological Activity** | Waste products can become acids through nitrification | Lowering |
| **Plants** | Absorption of CO2 during photosynthesis can change pH | Raising during photosynthesis; varies otherwise |
| **Nitrification** | Conversion of ammonia to nitrite and nitrate produces acids | Lowering |
| **Water Changes** | New water can adjust pH depending on its own pH  | Raising or Lowering |
| **Time and System Maturity**| Accumulation of organic acids from waste and decomposition | Lowering |
| **Alkalinity** | Buffering capacity neutralizes acids, stabilizing pH | Stabilizing, potentially lowering as capacity is exhausted |
| **Decomposition of Organic Matter** | Releases acidic compounds into the system | Lowering |
| **Aquaponic Media** | Type of media can leach substances that affect pH | Raising if calcareous materials are used |
| **Feed Type and Quantity**  | Influences waste production and subsequent nitrification | Indirectly lowering |

| Water Quality Parameter | Importance for Plants | Importance for Fish | High or Low Good? | Min-Max Range for Plants | Min-Max Range for Fish  |
|---|---|---|---|---|---|
| **Temperature (°C)** | Critical for metabolic processes | Essential for health and metabolism | Optimal range preferred | 18–29°C | 18–29°C |
| **pH** | Affects nutrient solubility and uptake | Affects respiratory efficiency and health | Stable is good | 6.0–7.0 | 6.0–9.0 (varies by species) |
| **Total Ammonia Nitrogen (TAN)** | Low levels prevent toxicity | High levels can be toxic | Low is good | < 1 mg/L | < 1 mg/L |
| **Nitrite (NO2)** | Low levels prevent toxicity | High levels can be toxic, affect oxygen transport | Low is good | < 1 mg/L | < 1 mg/L |
| **Nitrate (NO3)** | Primary nutrient, higher levels typically beneficial | High levels less toxic but should be controlled | High is good, but balanced | 5–150 mg/L | 5–150 mg/L |
| **Dissolved Oxygen (DO)** | Essential for root and bacterial health | Crucial for respiration | High is good | > 5 mg/L | > 5 mg/L |

| Source | Nutrients Provided | Description |
|---|---|---|
| **Fish Excretions**  | Ammonia (NH3), Nitrites (NO2), Nitrates (NO3) | Fish waste is converted by bacteria to forms usable by plants. |
| **Fish Feed** | Potassium (K), Phosphorus (P), Trace Elements | Nutrients in feed that are not fully digested are available to plants. |
| **Bacterial Activity** | Nitrates (NO3), Nitrites (NO2), other byproducts | Beneficial bacteria convert ammonia to nitrite and then nitrate. |
| **Fresh Water** | Various, depending on water source | Can occasionally introduce small amounts of nutrients or be used to adjust nutrient levels. |
| **Supplementation**  | Iron (Fe), Calcium (Ca), Magnesium (Mg), etc. | Directly added to the system to supplement deficiencies that affect plant growth. |

https://www.aquagardening.com.au/aquaponics/water-quality-ph-control/ammonia-testing/

__Note : Table needs to checked__

To explore further:
https://pubs.nmsu.edu/_circulars/CR680/

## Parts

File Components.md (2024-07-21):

Please if you need to shop for parts, it would be great that you use the supply links below. As they are affilated, you're supporting directly the development of Edward! Thank you!
The boards contains QWIIC connectors (3V3 Level). This allows to integrate many sensors from Adafruit or Sparkfun.

# Sensors

## Water Flow Meter 
<p align="center">

</p>

Device| Integration | Notes | Board Compatbility | ToDo | Source |
|---|---|---|---|---|---|
Flow Meter|PCTN Counter| ESP32 internal Counter ESPHOME ✅ | GreenHouse, Fishtank, SSR8 : Level Shifter Missing | Design Translator PCB & Formula | [Aliexpress](https://s.click.aliexpress.com/e/_DBCUJ6n)
Flow Meter|DS1683 | Event Counter on I2C | Helios : Not yet test | Develop Component Software | [Aliexpress](https://s.click.aliexpress.com/e/_DBCUJ6n)

## Level and Limit Switch
<p align="center">

</p>

| Device | Notes | Board Compatbility | ToDo | Source |
|---|---|---|---|---|
|Limit Switch| Can be used for Chicken Coop Door, Floating switch | Greenhouse & FishTank : L1 - L2 | Fully Tested ✅| 
|Sonar| Measure Distance to Water Surface | GreenHouse : Not yet tested | |
|Optical Water | Can not be fully submerged (Tank mounted) | Greenhouse & Fishtank | Fully Tested ✅|
|Fuel Gauge | Solid Design - 5 stage 0 - 190Ohm | GreenHouse & Fishtank : Thermistor - SSR Rebel on Analog | Fully Tested ✅|

## Temperature
<p align="center">

</p>

| Device | Notes | Board Compatbility | ToDo | Source |
|---|---|---|---|---|
|ds18b20| Digital One-Wire Temperature Sesnor | Greenhouse & FishTank & SSR | Fully Tested ✅ - Check Multiple Device|
|Thermistor| (10K)  | Greenhouse & FishTank & SSR8 &  | Not yet tested |

## Ambient & Air Quality
<p align="center">

</p>

| Device | Notes | Board Compatbility | ToDo | Source |
|---|---|---|---|---|
|BME680| Temperature, pressure, humidity, Quality sensor | Greenhouse & FishTank | Fully Tested ✅ -| [Aliexpress](https://s.click.aliexpress.com/e/_DBvNEJ5)

# Load Switching
## AC Switching
<p align="center">

</p>

| Device | Notes | Board Compatbility | ToDo | Source |
|---|---|---|---|---|
|Relay  | 5V 4 Channel  | Greenhouse with Relay - PCB  | Not yet Tested| [Aliexpress](https://s.click.aliexpress.com/e/_DFJCp8L)
|Solid State Relay | 8x 2Amp main SSR |Greenhouse with SSR - PCB  | Fully Tested ✅| [Aliexpress](https://s.click.aliexpress.com/e/_DkCJPYb)
|Dimmable Solid State Relay | 8x 2Amp main SSR | SSR Rebel with Zero Crossing Circuit  | Fully Tested ✅| Tindie Store soon

## DC Switching
<p align="center">

</p>

| Device | Notes | Board Compatbility | ToDo | Source |
|---|---|---|---|---|
|Blued Mosfet  | COTS Module  5-36V at 15Amp  | Greenhouse with GSV Mosfet Rail PCB - PIO1-4 | Not yet Tested ✅  | [Aliexpress](https://s.click.aliexpress.com/e/_DFgjmCX)
|Black Mosfet | COTS Module different options : 30V-100V min 30Amp|  Greenhouse with SVG Mosfet Rail PCB PIO1-4 | Fully Tested ✅| [Aliexpress](https://s.click.aliexpress.com/e/_Dl0jIYB)
|On Board Switch | Power Smart Switch |  Fishtank PIO1-4 | Fully Tested ✅|

## Motors & Actuators
<p align="center">

</p>

| Device | Notes | Board Compatbility | ToDo | Source |
|---|---|---|---|---|
|Water Pump  | AC  | Greenhouse with SSR or Relay - SSR Rebel (dimming not recommanend | Tested ✅  | 
|Water Pump  | DC  | Greenhouse with Mosfet Rail PCB - Fishtank Load Switch  | Not yet Tested |
|28BYJ48  | Geared Stepper Motor  | Greenhouse with GSV Mosfet Rail PCB - PIO1-4 | Not yet Tested  |
|Servo | PWM Controller  | Greenhouse & Fistank : Servo 1 2  | Not yet Tested  |
|Valve | AC DC  | Greenhouse with Load Rail PCB - PIO1-4 | Not yet Tested |
|Fan  | DC  | Greenhouse & Fish House PCTN - Helios EMC2102 Fan | Not yet Tested |

## Light
<p align="center">

</p>

| Device | Notes | Board Compatbility | ToDo | Source 
|---|---|---|---|---|
| Aquarium 8 Channels Module | COTS Module | Helios | Fully  Tested ✅|| [Aliexpress](https://s.click.aliexpress.com/e/_DFJCp8L)
| DC Led Driver Module | COTS Module )  | Helios : 1 ex. PWM Green House & Fishtank : Servo 1 - 2 | Fully  Tested ✅|| [Aliexpress](https://s.click.aliexpress.com/e/_DD5UYUn)
| LED 230AC | COTS Module (30-50 Watt) Different Wavelengts |  GreenHouse with SSR (On Off) - SSR Rebel (dimming)  | Fully Tested ✅| [Aliexpress](https://s.click.aliexpress.com/e/_DkCJPYb)

### Aquarium Module 8 Channel
<p align="center">
 
</p>
DC 3W 5-35V Led Driver Step Down : Exist for 350mA and 700mA.

* [Datasheet](https://www.led-stuebchen.de/download/PT4115E.pdf)
* [Aliexpress 1-3Watt Driver ](https://s.click.aliexpress.com/e/_DkGRYXz)
* [Aliexpress LED Module](https://de.aliexpress.com/item/1005002624762658.html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)

| Channel | Color | Wavelength (nm) | Current (mA) | Voltage (V) | Power (W) | Quantity |
|---|---|---|---|---|---|---|
| Red | Red | 650-670 | 700 | 4.0-4.4 | 2.94 | 2 |
| Green | Green | 520-530 | 700 | 6.0-6.4 | 4.34 | 2 |
| Deep Blue | Deep Blue| 450-470 | 700 | 12-13 | 8.75 | 4 |
| White | White | 6000-8000K | 700 | 12-13 | 8.75 | 4 |
| Yellow | Yellow | 585-595 | 700 | 2.0-2.2 | 1.47 | 1 |
| Violet | Violet | 410-430 | 700 | 12-13 | 8.75 | 3 |
| UV | UV | 390-410 | 700 | 6.4-6.6 | 4.55 | 2 |

__Theoretical Power Figures__
**Total Power Consumption:** 48.3W  
**Required Voltage for LED Driver:** 15V (safe margin)  
**Typical Step-Down LED Driver Input Voltage:** 24V
**Need to double check LED numbers and specifications**

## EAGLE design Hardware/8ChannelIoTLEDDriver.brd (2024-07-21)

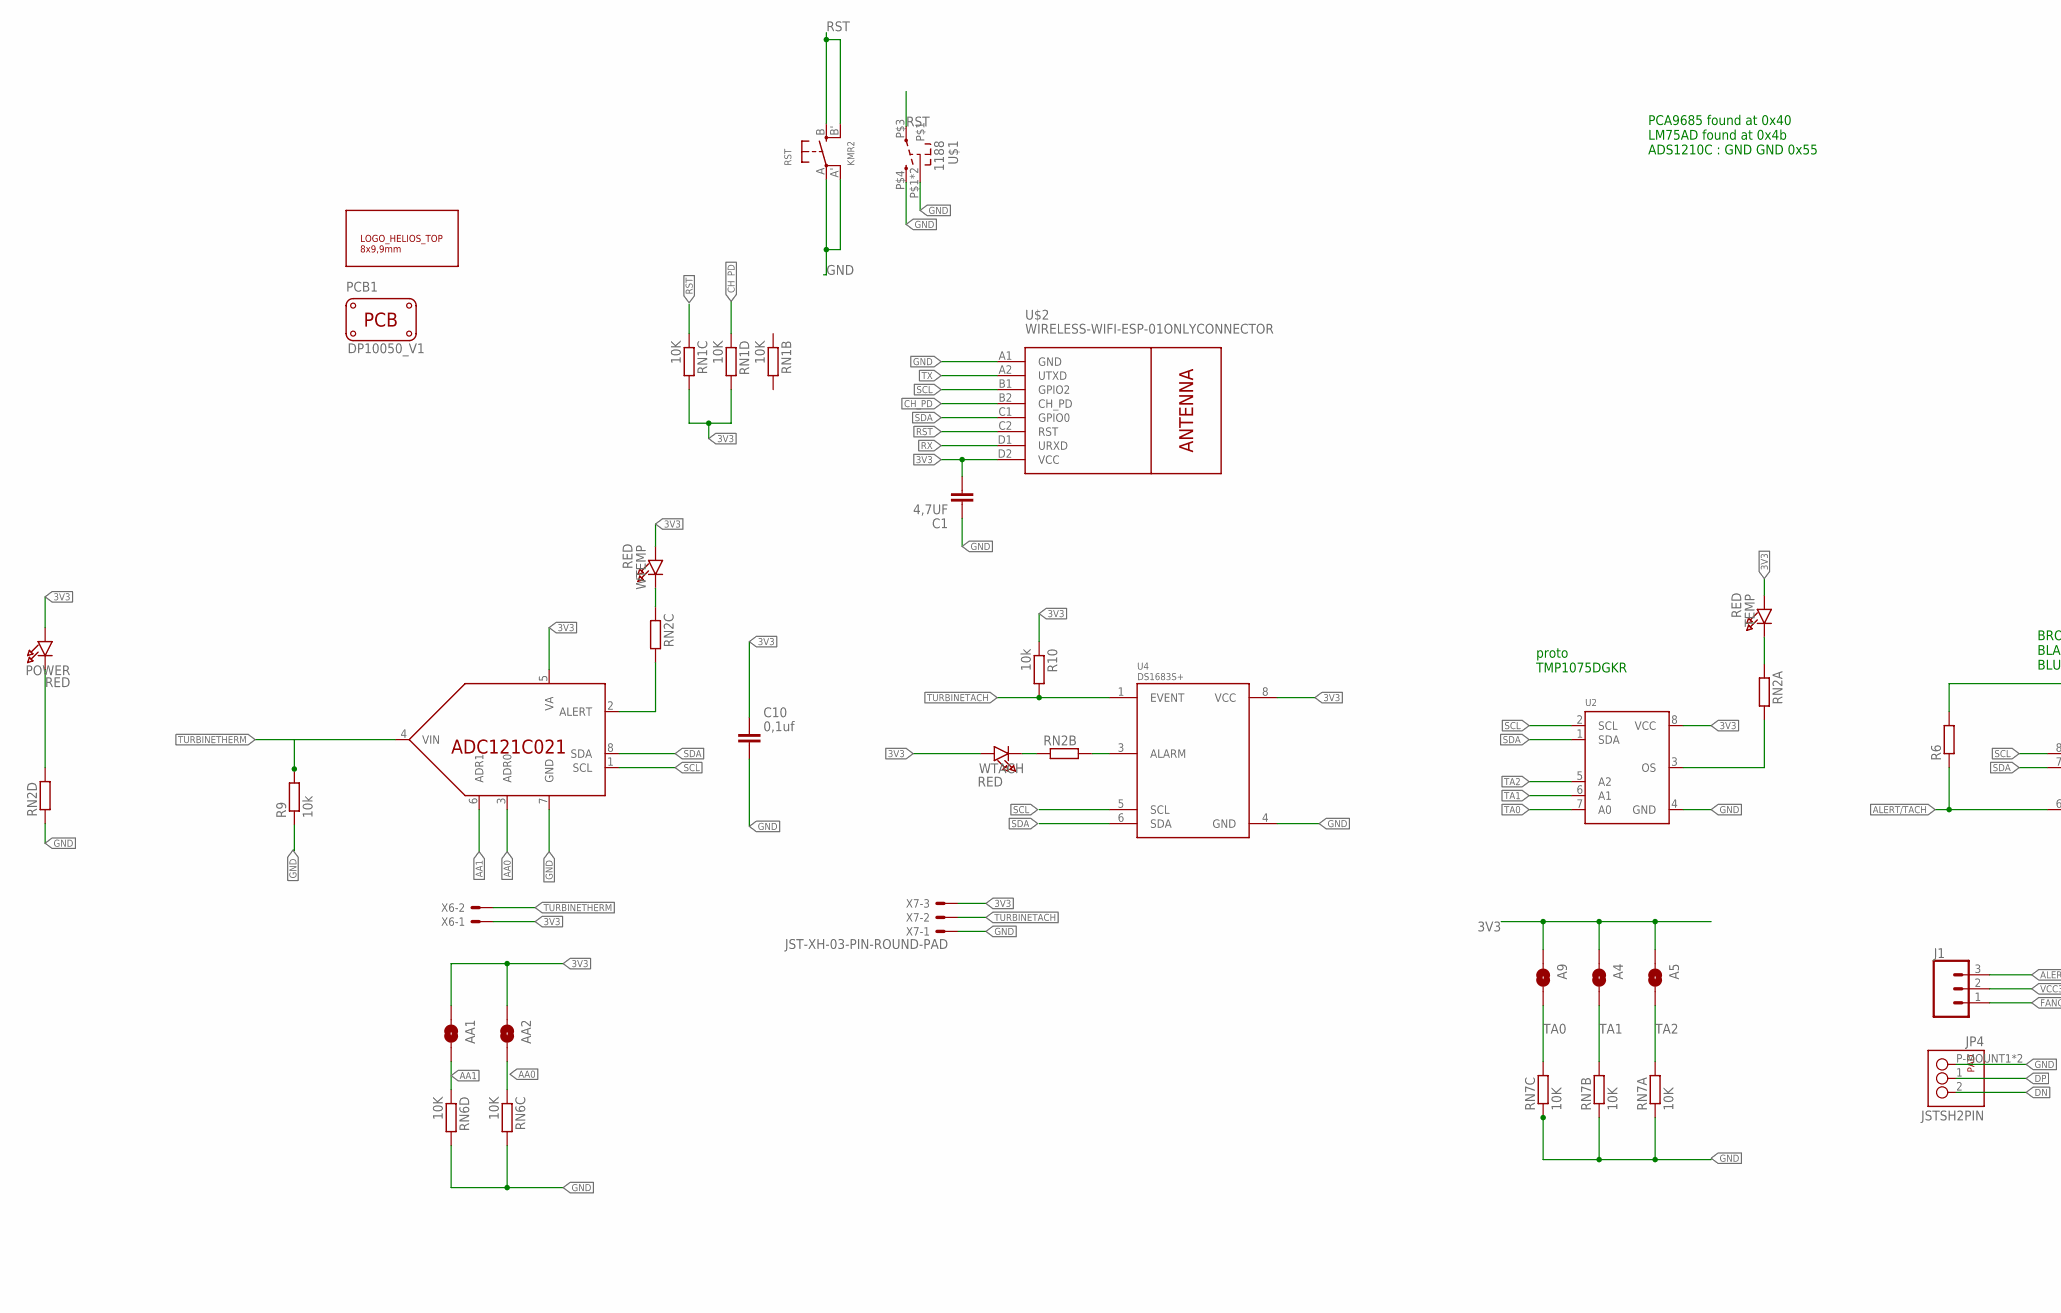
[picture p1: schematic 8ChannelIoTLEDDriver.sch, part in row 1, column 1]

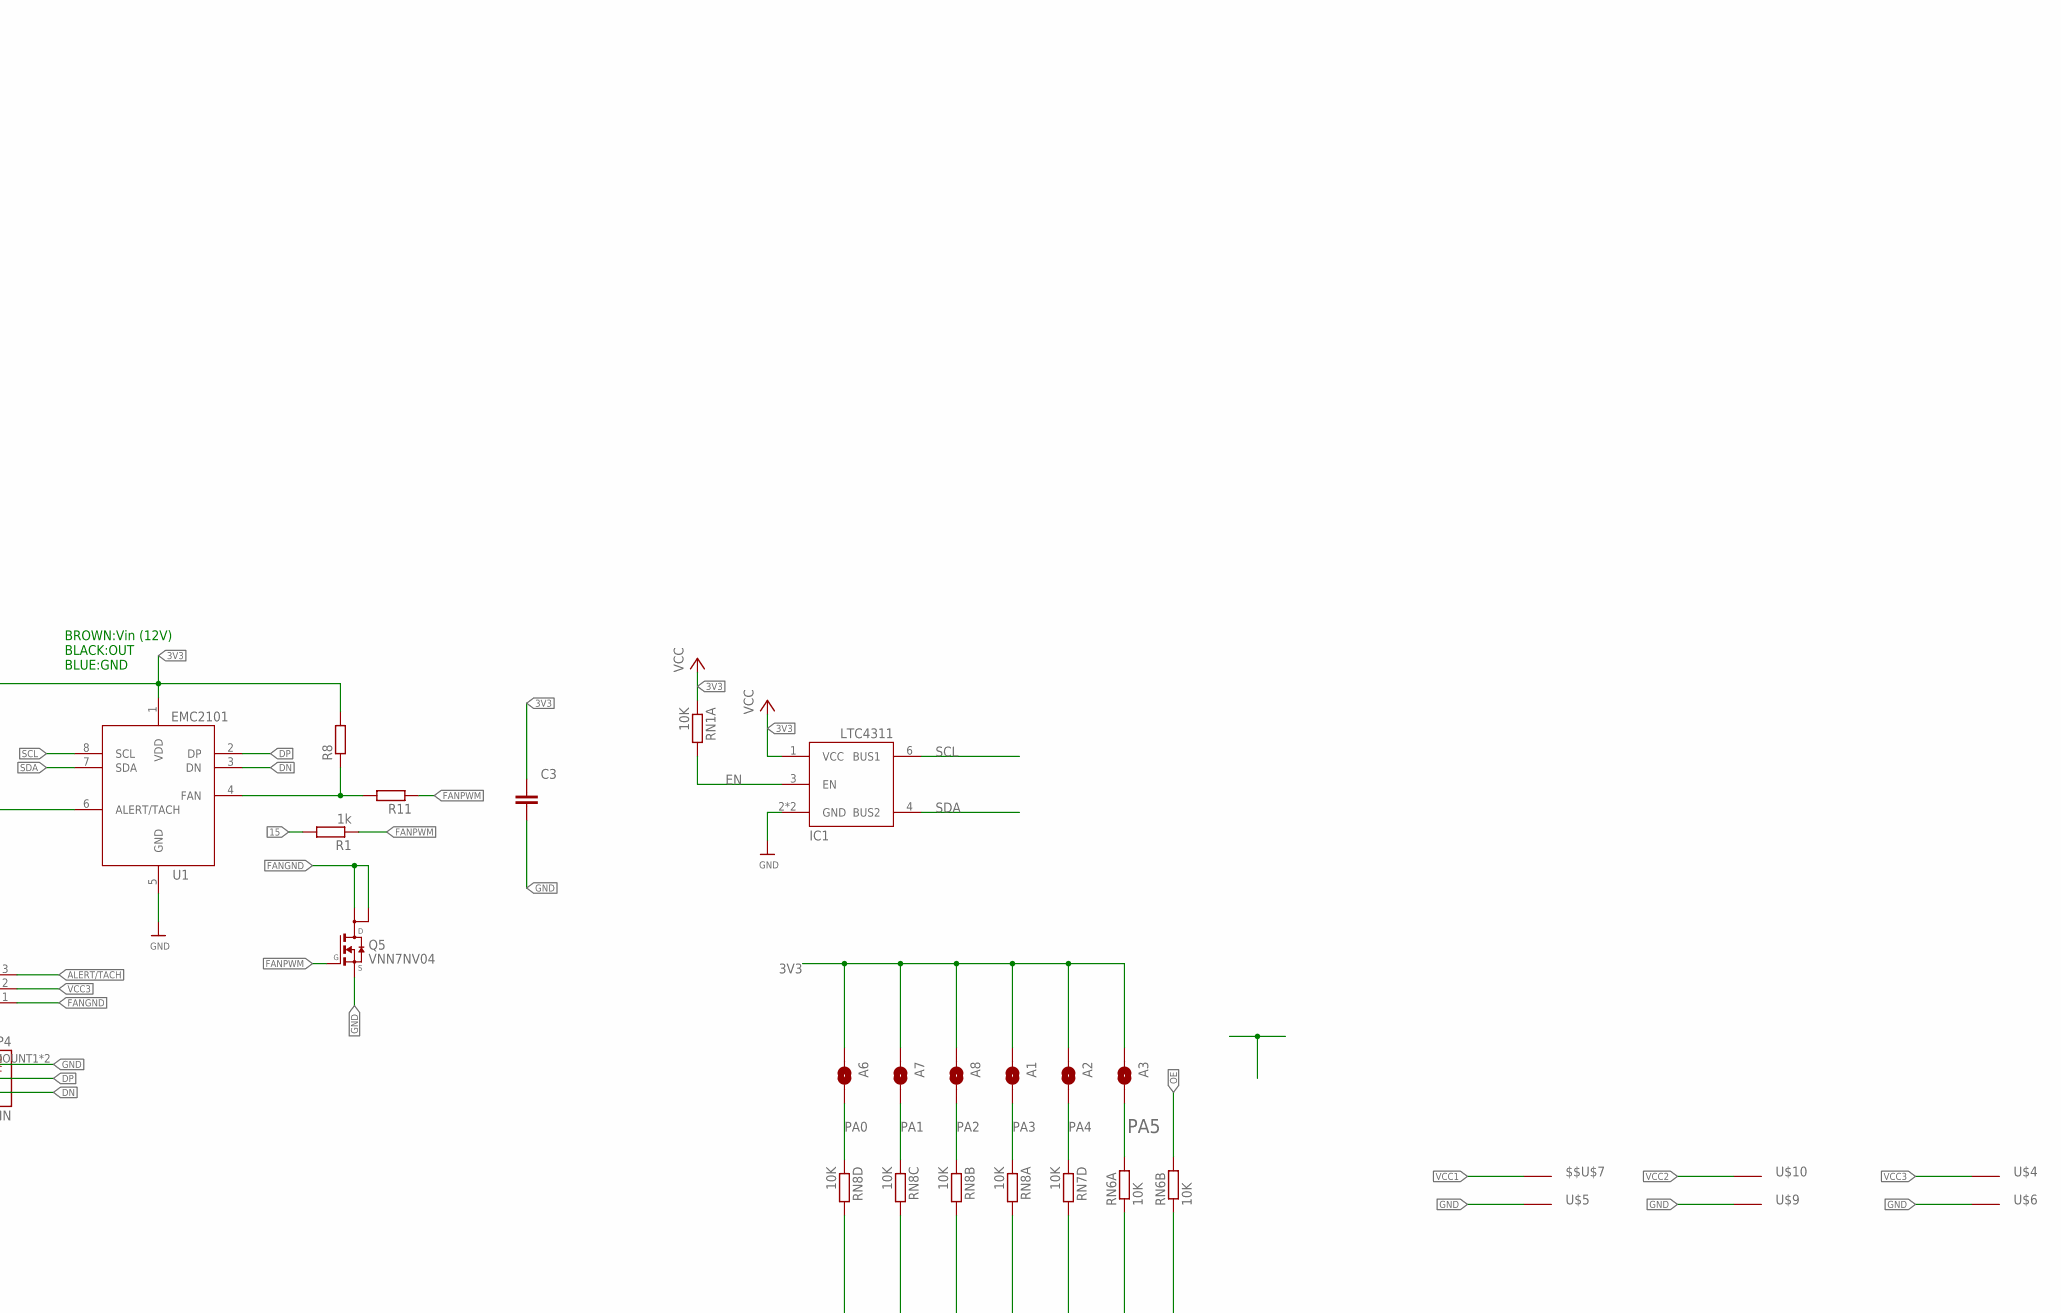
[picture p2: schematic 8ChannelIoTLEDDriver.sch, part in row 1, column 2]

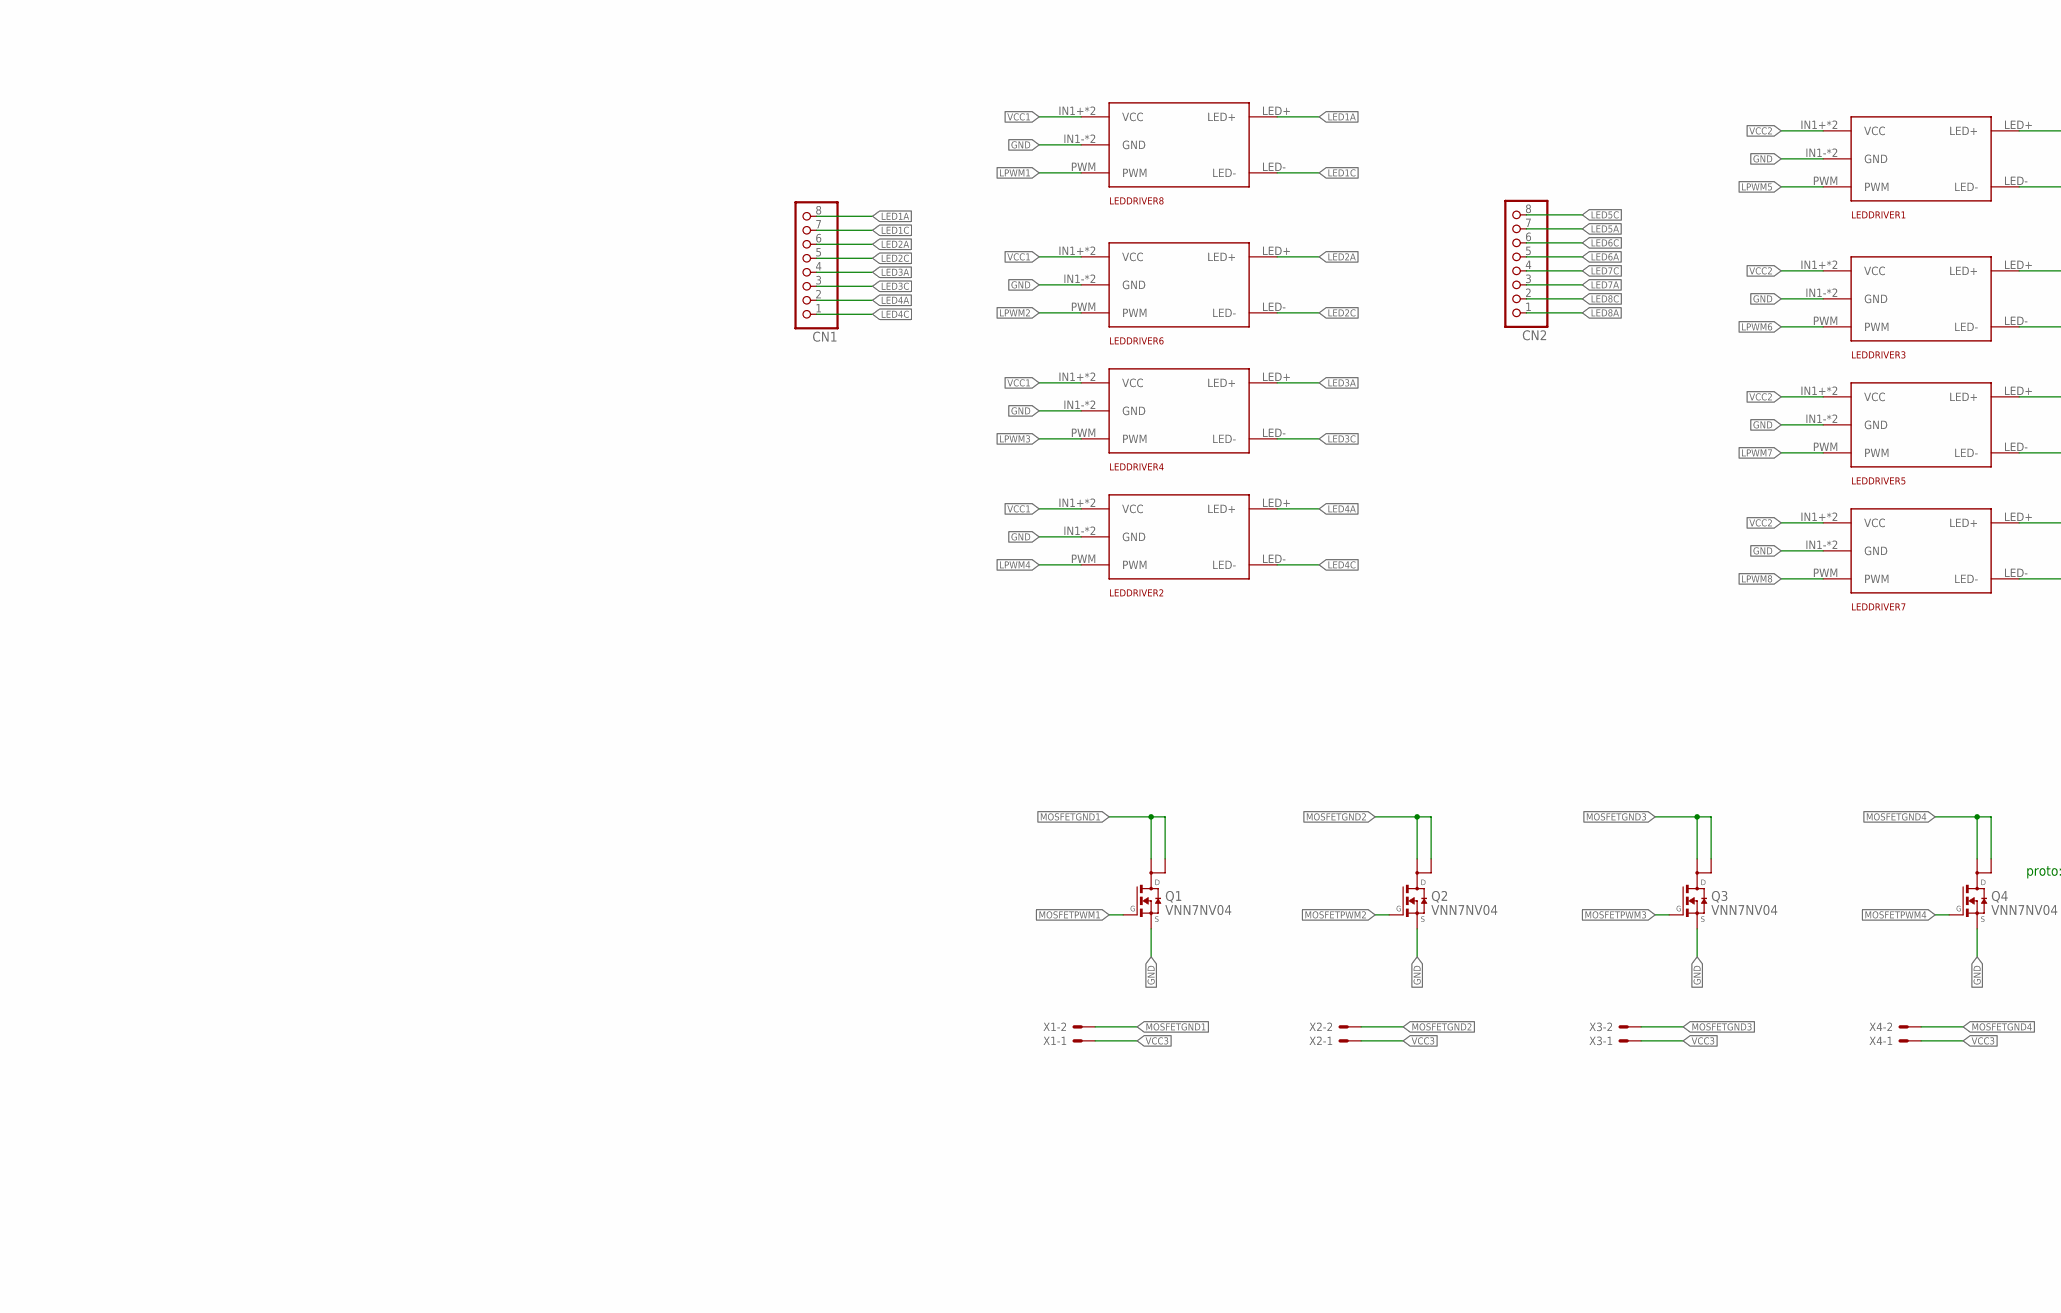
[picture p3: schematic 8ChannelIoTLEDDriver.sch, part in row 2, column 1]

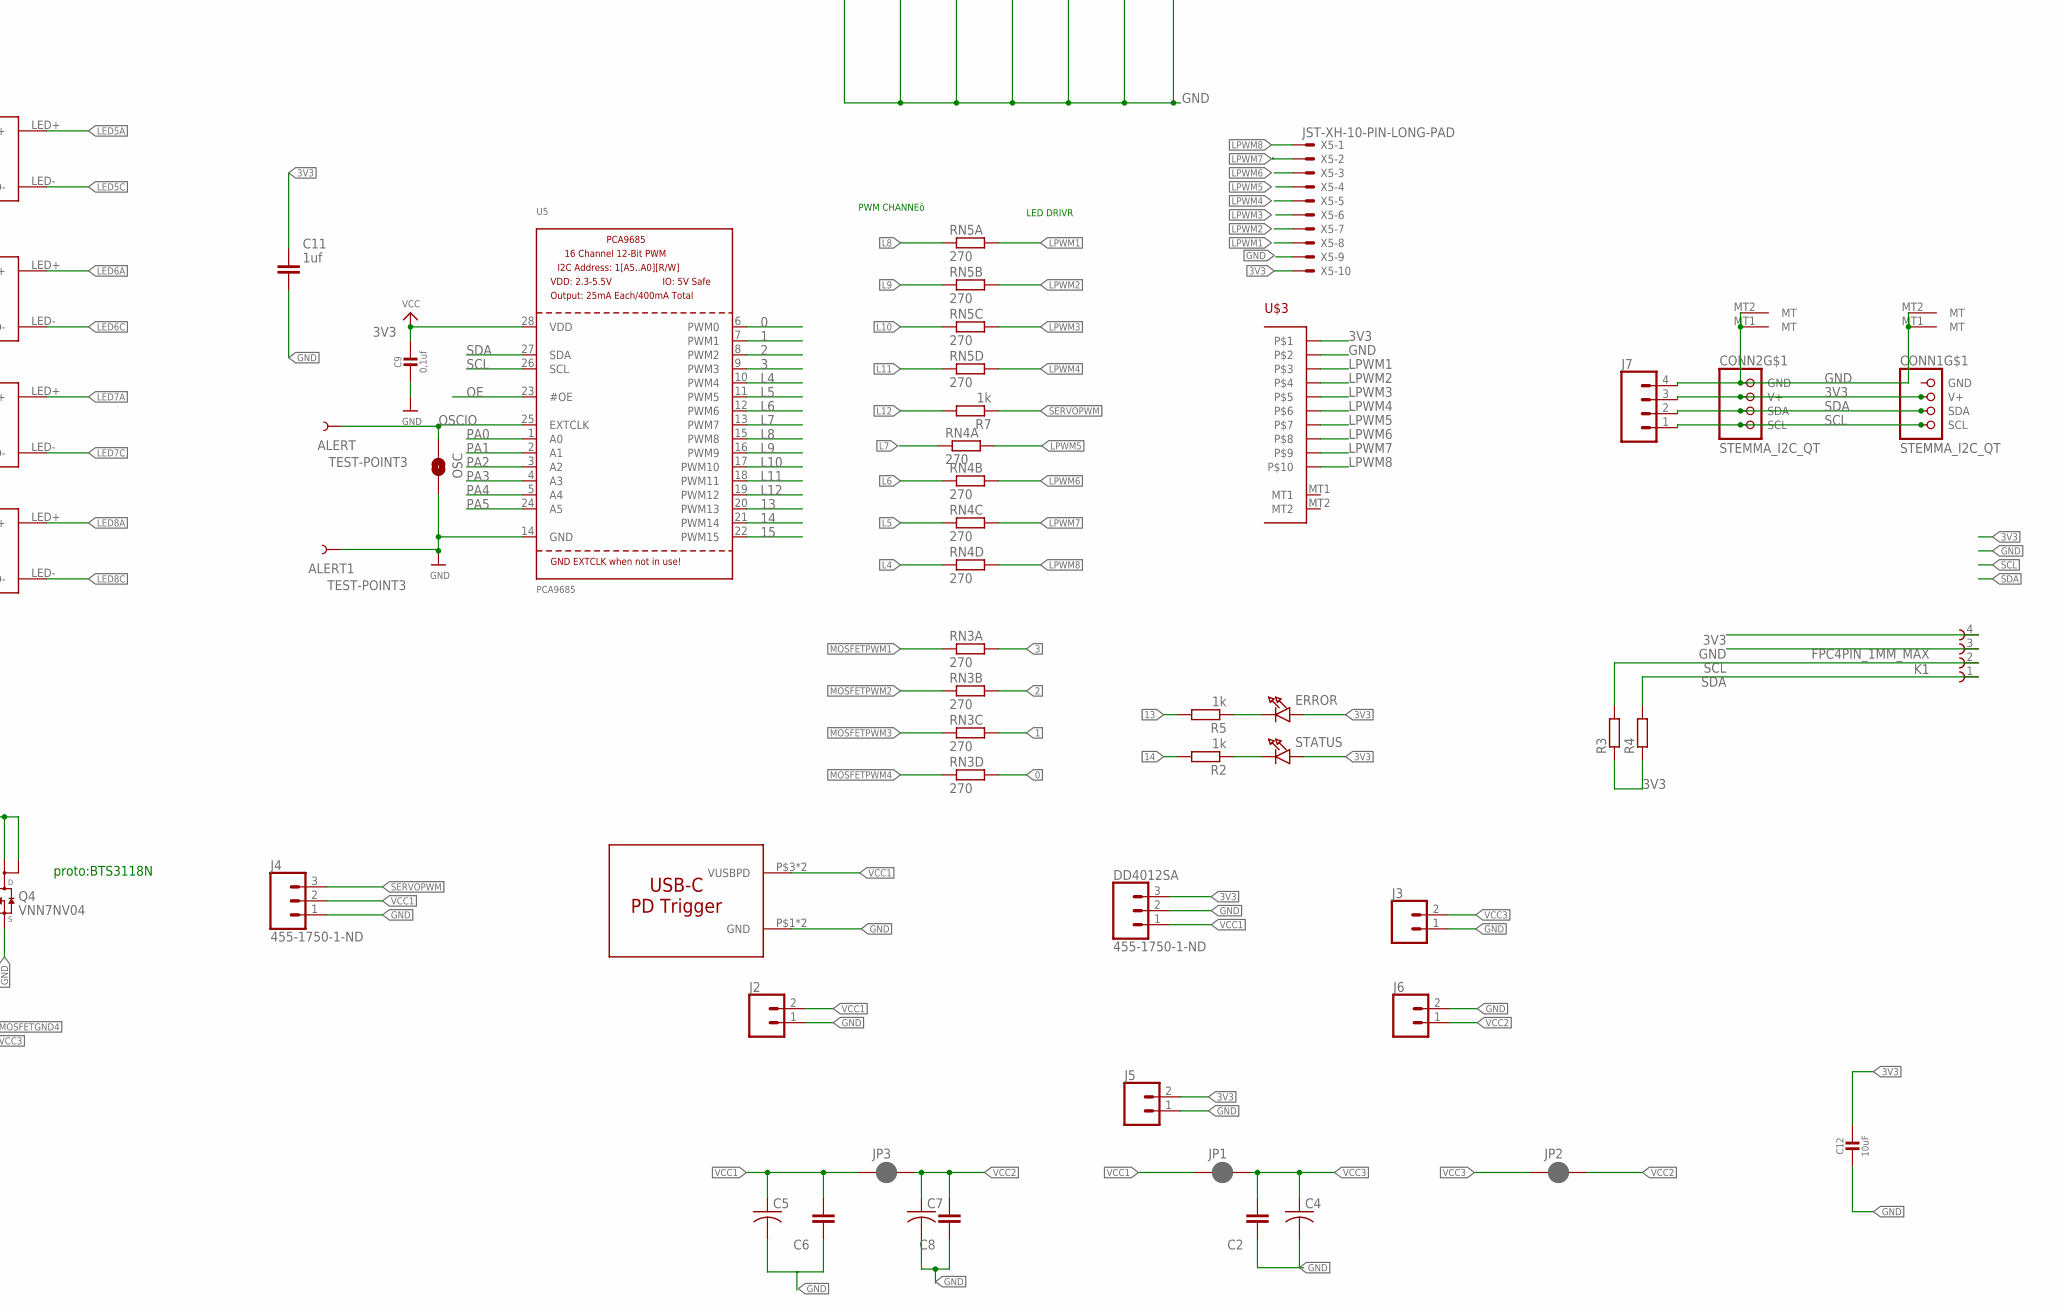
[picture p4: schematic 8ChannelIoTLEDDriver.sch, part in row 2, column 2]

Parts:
$$U$7: TESTHOOK
A1, A2, A3, A4, A5, A6, A7, A8, A9: JUMPER-SMT_2_NO_SILK; SMT-JUMPER_2_NO_SILK
AA1, AA2: JUMPER-SMT_2_NO_SILK; SMT-JUMPER_2_NO_SILK
ALERT, ALERT1: TEST-POINT3; PAD.03X.03
C1: 4,7UF; C805
C2, C3, C6, C8: CAPACITOR_NPOL-0805; C805
C4, C5, C7: C-USC1210; C1210
C9: 0,1uf; 0805-NO
C10: 0,1uf; C805
C11: 1uf; C805
C12: 10uF; 0805-NO
CN1, CN2: JST_8PIN; JSTPH8
CONN1, CONN2: STEMMA_I2C_QT; JST_SH4
DD4012SA: 455-1750-1-ND; 1X03
ERROR: RED; CHIPLED_0805
IC1: LTC4311_SC70; SC70-6L
J1: CONN_03POLAR; MOLEX-1X3
J2, J3, J5: CONN_02POLAR; MOLEX-1X2
J4: 455-1750-1-ND; 1X03
J6: CONN_023.5MM; SCREWTERMINAL-3.5MM-2
J7: CONN_04JST-PH-4-1.0MM; JST-4-SMD-VERT-1.0MM
JP1, JP2, JP3: JUMPER-SMT_2_NC_PASTE_SILK; SMT-JUMPER_2_NC_PASTE_SILK
JP4: JSTSH2PIN; SM02B-SRSS-TB
K1: FPC4PIN_1MM_MAX; FPC_CONN_DOC_4PIN_ENLARGED
LEDDRIVER1, LEDDRIVER2, LEDDRIVER3, LEDDRIVER4, LEDDRIVER5, LEDDRIVER6, LEDDRIVER7, LEDDRIVER8: LEDDRIVERPT4115LONG; 7PINLONGLEDDRIVER
OSC: JUMPER-SMT_2_NO_SILK; SMT-JUMPER_2_NO_SILK
PCB1: PCB_DP_RECTANGLE-50X100; DP10050_V1
POWER: RED; CHIPLED_0805
Q1, Q2, Q3, Q4, Q5: VNN7NV04; SOT223
R1, R2, R5, R7: 1k; R805
R3, R4, R6, R8, R11: RESISTORR805-0805; R805
R9, R10: 10k; R805
RN1, RN6, RN7, RN8: 10K; RN8P-4R-CRA06S
RN2: RESISTOR_ARRAY_4; RN8P-4R-CRA06S
RN3, RN4, RN5: 270; RN8P-4R-CRA06S
RST: KMR2; BTN_KMR2_4.6X2.8
STATUS: RED; CHIPLED_0805
TEMP: RED; CHIPLED_0805
U1: EMC2101-AZCL; MSOP8_0.65MM
U2: TEMP_LM75B; TSSOP8
U3: ADC121C021; MSOP08
U4: DS1683S+; SOIC8-N_MC
U5: PCA9685; TSSOP28
U$1: 1188
U$2: WIRELESS-WIFI-ESP-01ONLYCONNECTOR; WIRELESS-WIFI-ESP-01-ONLYBOTTOM
U$3: FPC-1.0X10; FPC_1.0X10
U$4, U$5, U$6, U$9, U$10: TESTHOOK
U$8: USB_PD_TRIGGER; USB-PDTRIGGER
U$11: LOGOTOPHELIOS
WTACH: RED; CHIPLED_0805
WTEMP: RED; CHIPLED_0805
X1, X2, X3, X4, X6: JST-XH-02-PIN-ROUND-PAD; JST-XH-02-PACKAGE-ROUND-PAD
X5: JST-XH-10-PIN-LONG-PAD; JST-XH-10-PACKAGE-LONG-PAD
X7: JST-XH-03-PIN-ROUND-PAD; JST-XH-03-PACKAGE-ROUND-PAD

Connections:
0: RN3.5 (2), U5.6 (PWM0)
1: RN3.6 (2), U5.7 (PWM1)
2: RN3.7 (2), U5.8 (PWM2)
3: RN3.8 (2), U5.9 (PWM3)
3V3: A1.1, A2.1, A3.1, A4.1, A5.1, A6.1, A7.1, A8.1, A9.1, AA1.1, AA2.1, C1.2, C3.1, C9.1, C10.1, C11.1, C12.1, CONN1.2 (V+), CONN2.2 (V+), DD4012SA.3, ERROR.A, IC1.1 (VCC), J5.2, J7.3, K1.4, POWER.A, R3.1, R4.1, R6.2, R8.2, R10.1, RN1.1, RN1.5 (2), RN1.6 (2), STATUS.A, TEMP.A, U1.1 (VDD), U2.8 (VCC), U3.5 (VA), U4.8 (VCC), U5.28 (VDD), U$2.D2 (VCC), U$3.1, WTACH.A, WTEMP.A, X5.10, X6.1, X7.3
13: R5.2, U5.20 (PWM13)
14: R2.2, U5.21 (PWM14)
15: R1.2, U5.22 (PWM15)
AA0: AA2.2, RN6.3 (1), U3.3 (ADR0)
AA1: AA1.2, RN6.4 (1), U3.6 (ADR1)
ALARM1: RN2.6 (2), U3.2 (ALERT)
ALARM2: RN2.8 (2), U2.3 (OS)
ALERT/TACH: J1.3, R6.1, U1.6 (ALERT/TACH)
CH_PD: RN1.4 (1), U$2.B2 (CH_PD)
DN: JP4.2, U1.3 (DN)
DP: JP4.1, U1.2 (DP)
EN: IC1.3 (EN), RN1.8 (2)
FANGND: J1.1, Q5.2 (D), Q5.4 (D2)
FANPWM: Q5.1 (G), R1.1, R11.1
GND: ALERT1.P$1, C1.1, C2.1, C3.2, C4.2, C5.2, C6.1, C7.2, C8.1, C9.2, C10.2, C11.2, C12.2, CONN1.MT1 (MT), CONN1.MT2 (MT), CONN2.1 (GND), CONN2.MT1 (MT), CONN2.MT2 (MT), DD4012SA.2, IC1.2 (GND), IC1.5 (GND), J2.1, J3.1, J4.1, J5.1, J6.2, J7.4, JP4.P-MOUNT1, JP4.P-MOUNT2, K1.3, LEDDRIVER1.IN1- (GND), LEDDRIVER1.IN2- (GND), LEDDRIVER2.IN1- (GND), LEDDRIVER2.IN2- (GND), LEDDRIVER3.IN1- (GND), LEDDRIVER3.IN2- (GND), LEDDRIVER4.IN1- (GND), LEDDRIVER4.IN2- (GND), LEDDRIVER5.IN1- (GND), LEDDRIVER5.IN2- (GND), LEDDRIVER6.IN1- (GND), LEDDRIVER6.IN2- (GND), LEDDRIVER7.IN1- (GND), LEDDRIVER7.IN2- (GND), LEDDRIVER8.IN1- (GND), LEDDRIVER8.IN2- (GND), OSC.2, Q1.3 (S), Q2.3 (S), Q3.3 (S), Q4.3 (S), Q5.3 (S), R9.1, RN2.4 (1), RN6.1, RN6.2 (1), RN6.5 (2), RN6.6 (2), RN7.1, RN7.2 (1), RN7.3 (1), RN7.5 (2), RN8.5 (2), RN8.6 (2), RN8.7 (2), RN8.8 (2), RST.A, RST.A' (P1), U1.5 (GND), U2.4 (GND), U3.7 (GND), U4.4 (GND), U5.14 (GND), U$1.P$1, U$1.P$2, U$1.P$4 (3), U$2.A1 (GND), U$3.2, U$5.P$1, U$6.P$1, U$8.P$1 (GND), U$8.P$2 (GND), U$9.P$1, X5.9, X7.1
L4: RN4.4 (1), U5.10 (PWM4)
L5: RN4.3 (1), U5.11 (PWM5)
L6: RN4.2 (1), U5.12 (PWM6)
L7: RN4.1, U5.13 (PWM7)
L8: RN5.1, U5.15 (PWM8)
L9: RN5.2 (1), U5.16 (PWM9)
L10: RN5.3 (1), U5.17 (PWM10)
L11: RN5.4 (1), U5.18 (PWM11)
L12: R7.2, U5.19 (PWM12)
LED1A: CN1.8, LEDDRIVER8.LED+
LED1C: CN1.7, LEDDRIVER8.LED-
LED2A: CN1.6, LEDDRIVER6.LED+
LED2C: CN1.5, LEDDRIVER6.LED-
LED3A: CN1.4, LEDDRIVER4.LED+
LED3C: CN1.3, LEDDRIVER4.LED-
LED4A: CN1.2, LEDDRIVER2.LED+
LED4C: CN1.1, LEDDRIVER2.LED-
LED5A: CN2.7, LEDDRIVER1.LED+
LED5C: CN2.8, LEDDRIVER1.LED-
LED6A: CN2.5, LEDDRIVER3.LED+
LED6C: CN2.6, LEDDRIVER3.LED-
LED7A: CN2.3, LEDDRIVER5.LED+
LED7C: CN2.4, LEDDRIVER5.LED-
LED8A: CN2.1, LEDDRIVER7.LED+
LED8C: CN2.2, LEDDRIVER7.LED-
LPWM1: LEDDRIVER8.PWM, RN5.8 (2), U$3.3, X5.8
LPWM2: LEDDRIVER6.PWM, RN5.7 (2), U$3.4, X5.7
LPWM3: LEDDRIVER4.PWM, RN5.6 (2), U$3.5, X5.6
LPWM4: LEDDRIVER2.PWM, RN5.5 (2), U$3.6, X5.5
LPWM5: LEDDRIVER1.PWM, RN4.8 (2), U$3.7, X5.4
LPWM6: LEDDRIVER3.PWM, RN4.7 (2), U$3.8, X5.3
LPWM7: LEDDRIVER5.PWM, RN4.6 (2), U$3.9, X5.2
LPWM8: LEDDRIVER7.PWM, RN4.5 (2), U$3.10, X5.1
MOSFETGND1: Q1.2 (D), Q1.4 (D2), X1.2
MOSFETGND2: Q2.2 (D), Q2.4 (D2), X2.2
MOSFETGND3: Q3.2 (D), Q3.4 (D2), X3.2
MOSFETGND4: Q4.2 (D), Q4.4 (D2), X4.2
MOSFETPWM1: Q1.1 (G), RN3.1
MOSFETPWM2: Q2.1 (G), RN3.2 (1)
MOSFETPWM3: Q3.1 (G), RN3.3 (1)
MOSFETPWM4: Q4.1 (G), RN3.4 (1)
unnamed: RN2.1, TEMP.C
unnamed: RN2.2 (1), WTACH.C
unnamed: RN2.3 (1), WTEMP.C
unnamed: RN2.7 (2), U4.3 (ALARM)
unnamed: POWER.C, RN2.5 (2)
unnamed: R8.1, R11.2, U1.4 (FAN)
unnamed: R2.1, STATUS.C
unnamed: ERROR.C, R5.1
OE: RN6.7 (2), U5.23 (#OE)
OSCIO: ALERT.P$1, OSC.1, U5.25 (EXTCLK)
PA0: A6.2, RN8.4 (1), U5.1 (A0)
PA1: A7.2, RN8.3 (1), U5.2 (A1)
PA2: A8.2, RN8.2 (1), U5.3 (A2)
PA3: A1.2, RN8.1, U5.4 (A3)
PA4: A2.2, RN7.4 (1), U5.5 (A4)
PA5: A3.2, RN6.8 (2), U5.24 (A5)
RST: RN1.3 (1), RST.B (S), RST.B' (S1), U$1.P$3 (1), U$2.C2 (RST)
RX: U$2.D1 (URXD)
SCL: CONN1.4 (SCL), CONN2.4 (SCL), IC1.6 (BUS1), J7.1, K1.2, R3.2, U1.8 (SCL), U2.2 (SCL), U3.1 (SCL), U4.5 (SCL), U5.26 (SCL), U$2.B1 (GPIO2)
SDA: CONN1.3 (SDA), CONN2.3 (SDA), IC1.4 (BUS2), J7.2, K1.1, R4.2, U1.7 (SDA), U2.1 (SDA), U3.8 (SDA), U4.6 (SDA), U5.27 (SDA), U$2.C1 (GPIO0)
SERVOPWM: J4.3, R7.1
TA0: A9.2, RN7.6 (2), U2.7 (A0)
TA1: A4.2, RN7.7 (2), U2.6 (A1)
TA2: A5.2, RN7.8 (2), U2.5 (A2)
TURBINETACH: R10.2, U4.1 (EVENT), X7.2
TURBINETHERM: R9.2, U3.4 (VIN), X6.2
TX: U$2.A2 (UTXD)
VCC1: $$U$7.P$1, C5.1, C6.2, DD4012SA.1, J2.2, J4.2, JP1.1, JP3.1, LEDDRIVER2.IN1+ (VCC), LEDDRIVER2.IN2+ (VCC), LEDDRIVER4.IN1+ (VCC), LEDDRIVER4.IN2+ (VCC), LEDDRIVER6.IN1+ (VCC), LEDDRIVER6.IN2+ (VCC), LEDDRIVER8.IN1+ (VCC), LEDDRIVER8.IN2+ (VCC), U$8.P$3 (VUSBPD), U$8.P$4 (VUSBPD)
VCC2: C7.1, C8.2, J6.1, JP2.2, JP3.2, LEDDRIVER1.IN1+ (VCC), LEDDRIVER1.IN2+ (VCC), LEDDRIVER3.IN1+ (VCC), LEDDRIVER3.IN2+ (VCC), LEDDRIVER5.IN1+ (VCC), LEDDRIVER5.IN2+ (VCC), LEDDRIVER7.IN1+ (VCC), LEDDRIVER7.IN2+ (VCC), U$10.P$1
VCC3: C2.2, C4.1, J1.2, J3.2, JP1.2, JP2.1, U$4.P$1, X1.1, X2.1, X3.1, X4.1

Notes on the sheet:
BROWN:Vin (12V) BLACK:OUT BLUE:GND
PCA9685 found at 0x40 LM75AD found at 0x4b ADS1210C : GND GND 0x55
LED DRIVR
PWM CHANNEö
proto:BTS3118N
proto TMP1075DGKR

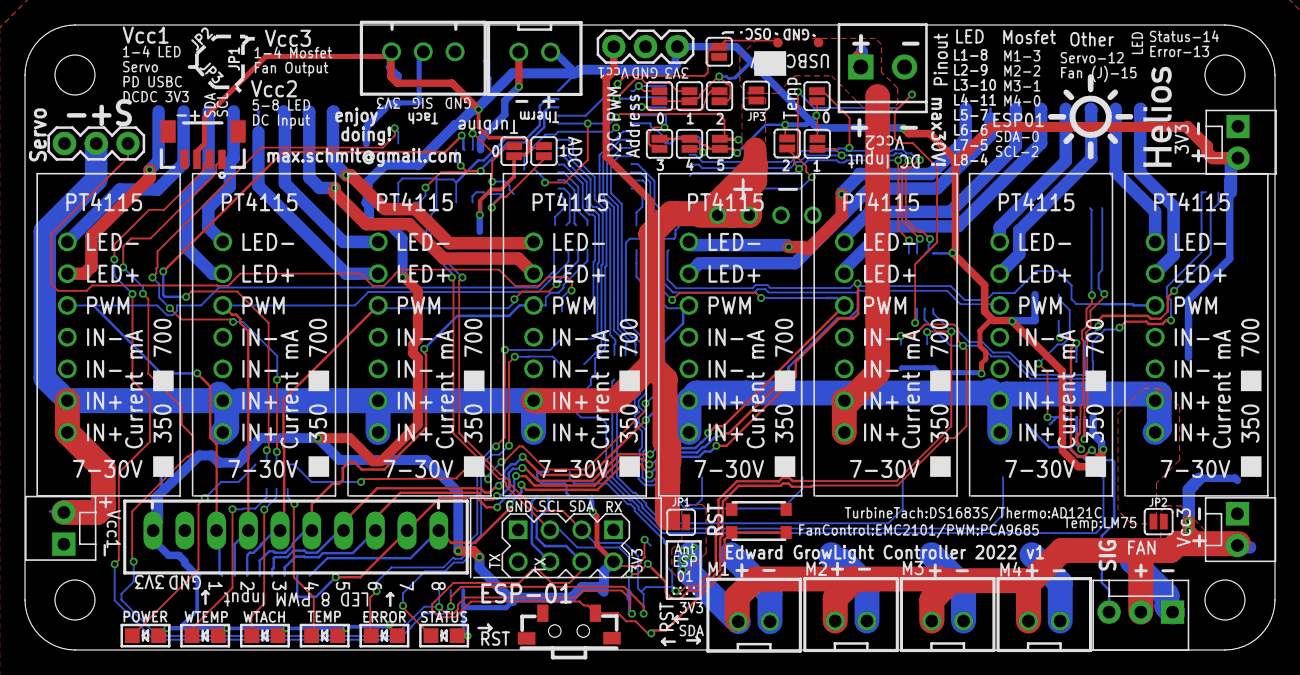
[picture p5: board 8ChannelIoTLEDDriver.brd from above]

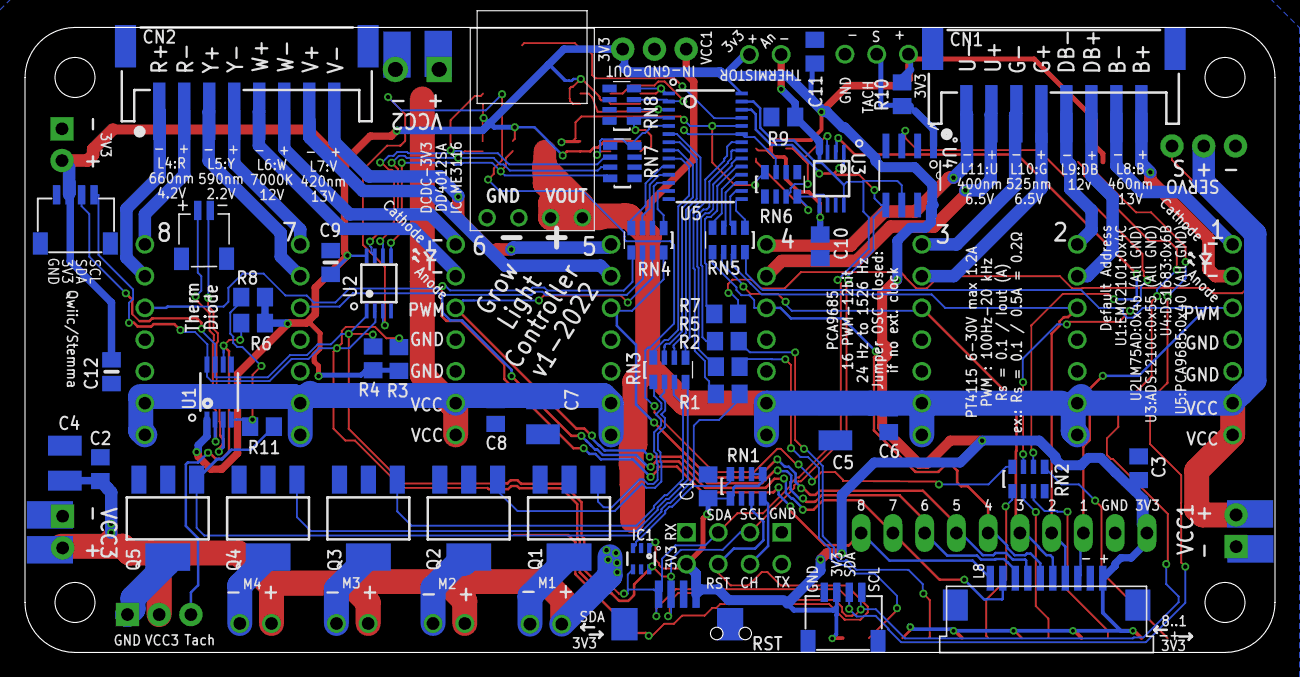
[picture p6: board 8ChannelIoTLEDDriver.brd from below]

Board: 2 copper layers, 100.0 x 50.0 mm, 107 parts (56 on the bottom side), 89 nets.

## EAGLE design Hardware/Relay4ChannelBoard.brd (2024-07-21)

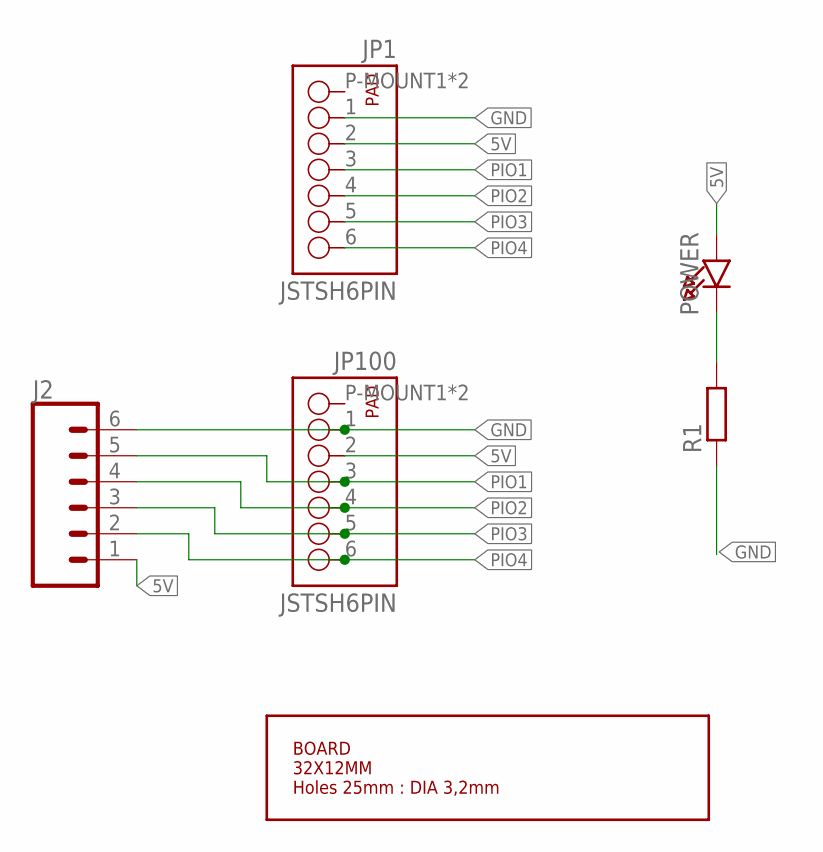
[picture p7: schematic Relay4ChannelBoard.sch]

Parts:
J2: CONN_06SILK_FEMALE_PTH; 1X06
JP1, JP100: JSTSH6PIN; SM06B-SRSS-TB
POWER: RED; CHIPLED_0805
R1: RESISTORR805-0805; R805
U$1: BOARD32X12; OVAL3212MM

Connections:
5V: J2.1, JP1.2, JP100.2, POWER.A
GND: J2.6, JP1.1, JP100.1, R1.1
unnamed: POWER.C, R1.2
PIO1: J2.5, JP1.3, JP100.3
PIO2: J2.4, JP1.4, JP100.4
PIO3: J2.3, JP1.5, JP100.5
PIO4: J2.2, JP1.6, JP100.6

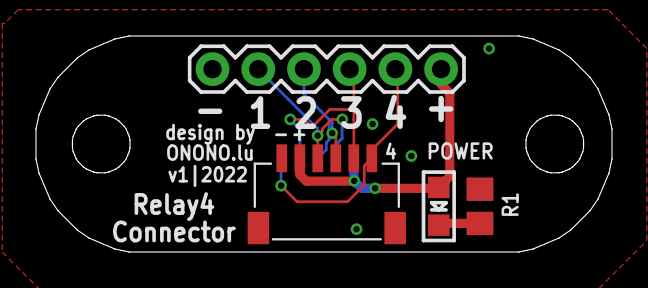
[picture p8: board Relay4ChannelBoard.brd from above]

Board: 2 copper layers, 32.0 x 12.0 mm, 6 parts (1 on the bottom side), 7 nets.

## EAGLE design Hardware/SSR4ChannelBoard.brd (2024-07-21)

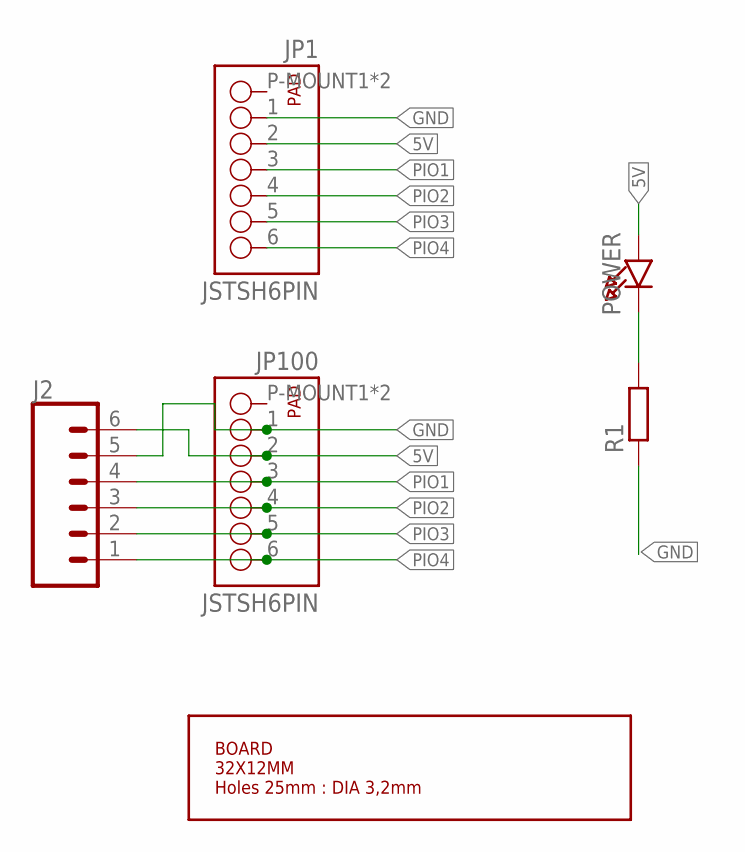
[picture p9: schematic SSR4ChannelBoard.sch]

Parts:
J2: CONN_06SILK_FEMALE_PTH; 1X06
JP1, JP100: JSTSH6PIN; SM06B-SRSS-TB
POWER: RED; CHIPLED_0805
R1: RESISTORR805-0805; R805
U$1: BOARD32X12; OVAL3212MM

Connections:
5V: J2.6, JP1.2, JP100.2, POWER.A
GND: J2.5, JP1.1, JP100.1, R1.1
unnamed: POWER.C, R1.2
PIO1: J2.4, JP1.3, JP100.3
PIO2: J2.3, JP1.4, JP100.4
PIO3: J2.2, JP1.5, JP100.5
PIO4: J2.1, JP1.6, JP100.6

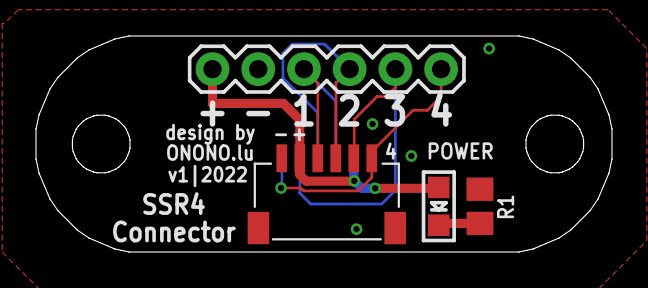
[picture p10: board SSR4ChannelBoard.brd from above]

Board: 2 copper layers, 32.0 x 12.0 mm, 6 parts (1 on the bottom side), 7 nets.

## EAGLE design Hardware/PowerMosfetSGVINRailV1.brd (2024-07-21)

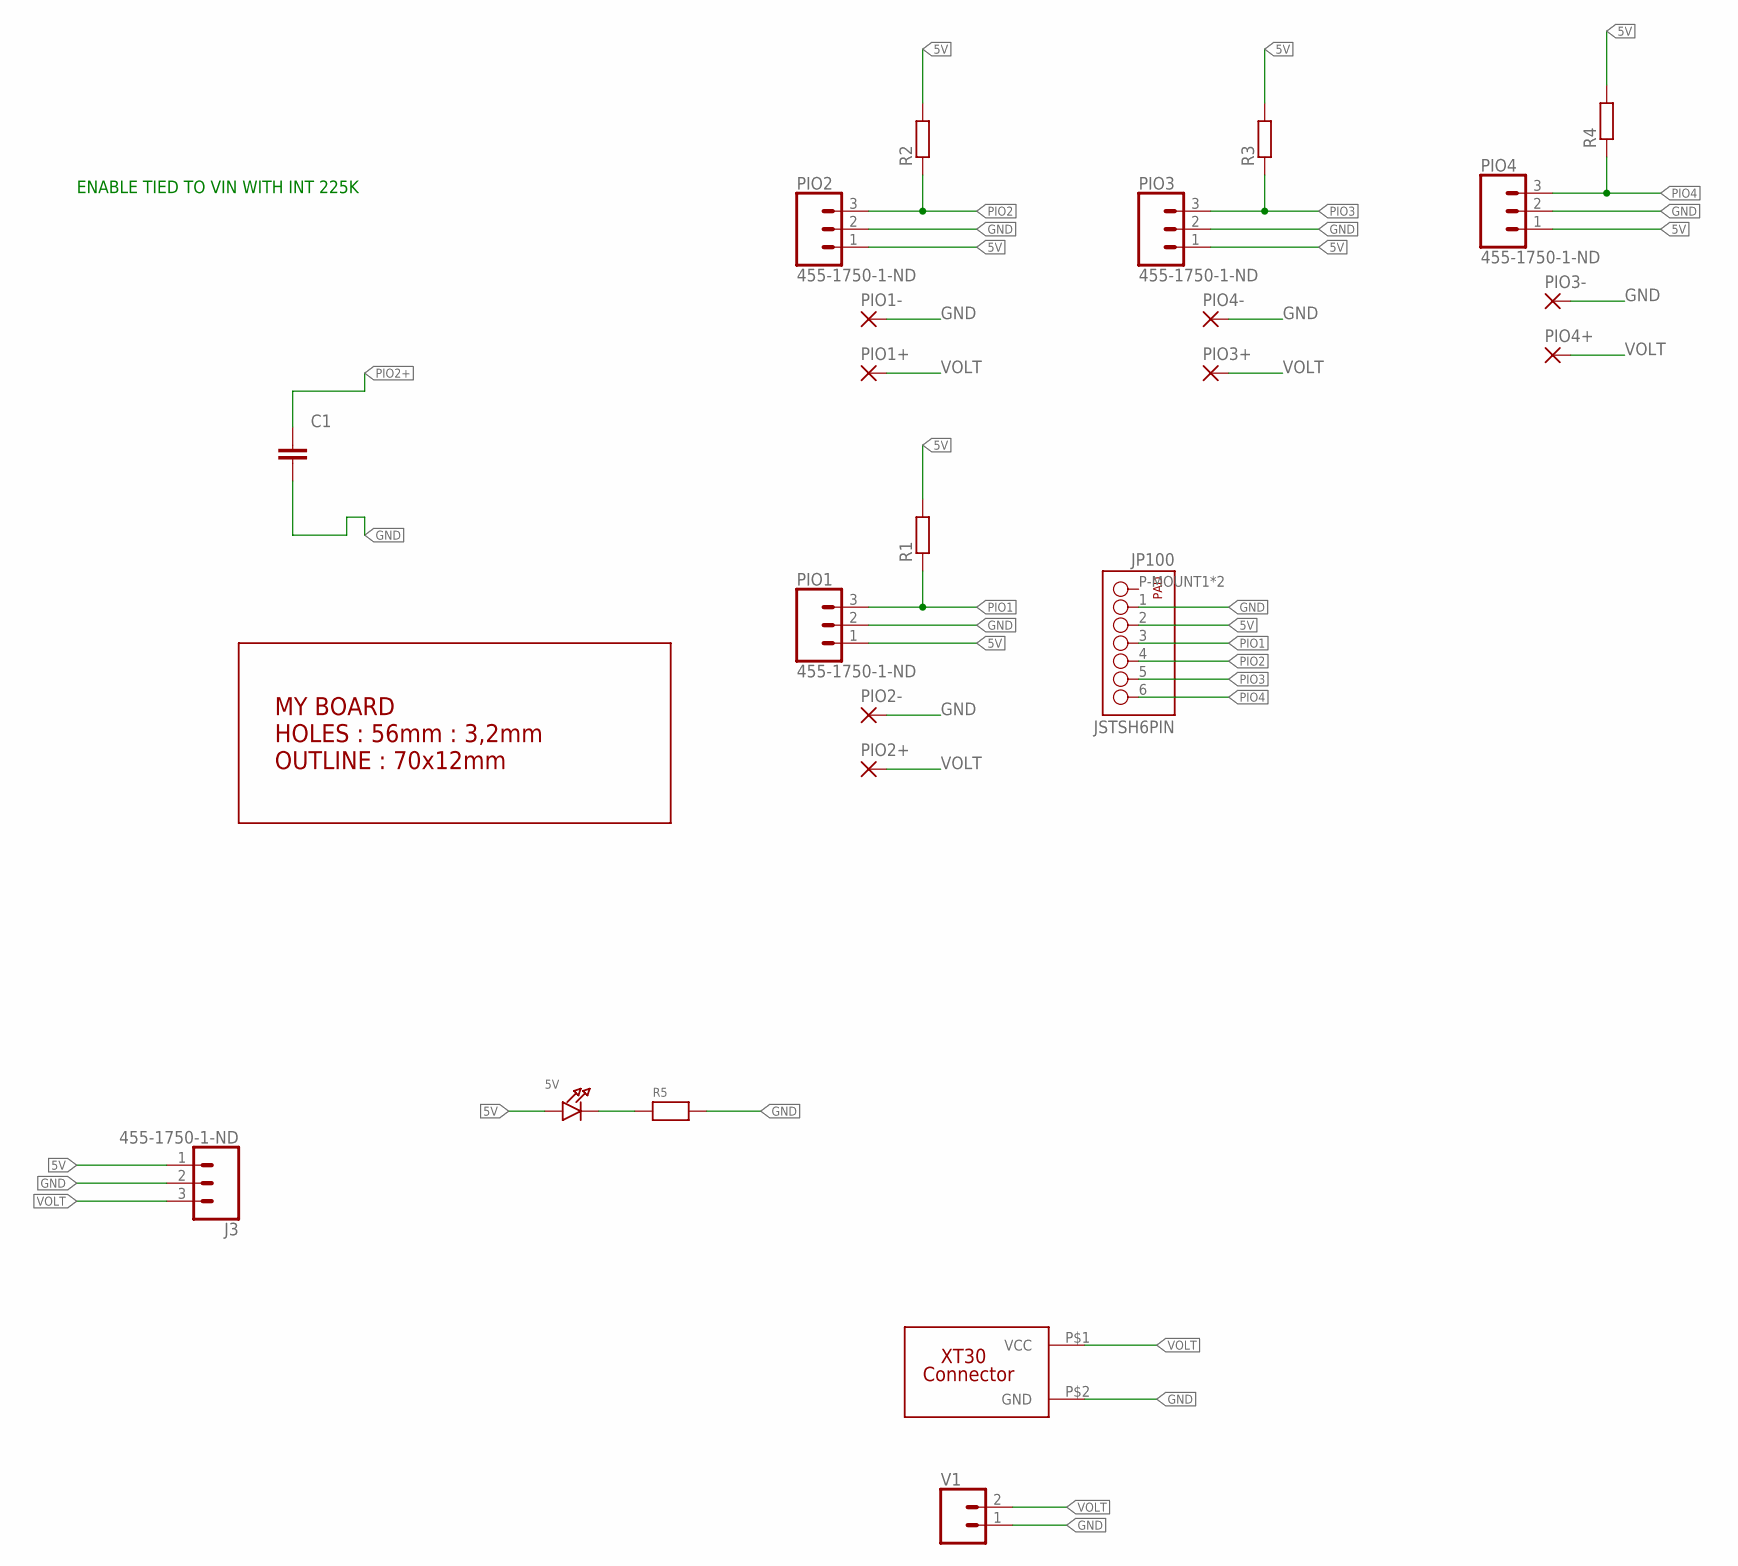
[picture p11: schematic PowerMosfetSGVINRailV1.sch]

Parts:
5V: LED0805; CHIPLED_0805
C1: CAPACITOR_NPOL-0805; C805
J3: 455-1750-1-ND; 1X03
JP100: JSTSH6PIN; SM06B-SRSS-TB
PIO1, PIO2, PIO3, PIO4: 455-1750-1-ND; 1X03
PIO1+, PIO1-, PIO2+, PIO2-, PIO3+, PIO3-, PIO4+, PIO4-: 3,17/1,3
R1, R2, R3, R4: RESISTORR805-0805; R805
R5: RESISTOR0805; 0805
U$2: BOARD70X12HOES; BOARD70X12
U$6: XT30; XT30-VERT
V1: CONN_023.5MM; SCREWTERMINAL-3.5MM-2

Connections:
5V: 5V.A, J3.1, JP100.2, PIO1.1, PIO2.1, PIO3.1, PIO4.1, R1.2, R2.2, R3.2, R4.2
GND: C1.2, J3.2, JP100.1, PIO1.2, PIO1-.1, PIO2.2, PIO2-.1, PIO3.2, PIO3-.1, PIO4.2, PIO4-.1, R5.2, U$6.P$2 (GND), V1.1
unnamed: 5V.C, R5.1
PIO1: JP100.3, PIO1.3, R1.1
PIO2: JP100.4, PIO2.3, R2.1
PIO2+: C1.1
PIO3: JP100.5, PIO3.3, R3.1
PIO4: JP100.6, PIO4.3, R4.1
VOLT: J3.3, PIO1+.1, PIO2+.1, PIO3+.1, PIO4+.1, U$6.P$1 (VCC), V1.2

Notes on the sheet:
ENABLE TIED TO VIN WITH INT 225K

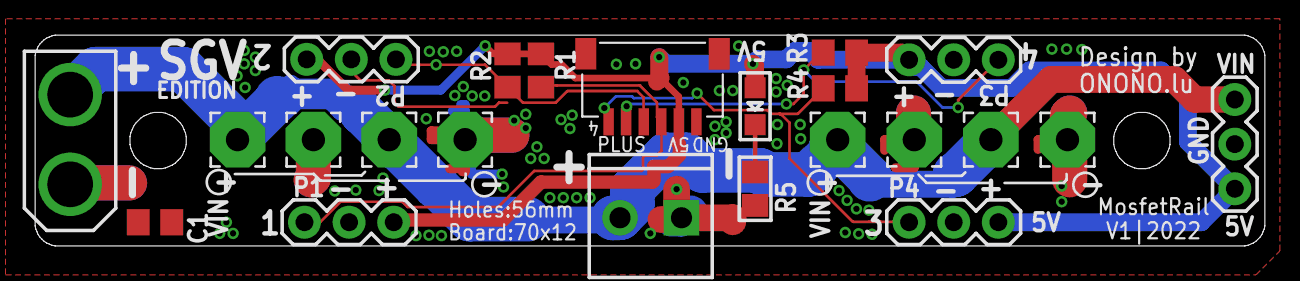
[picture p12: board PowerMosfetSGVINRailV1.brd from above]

Board: 2 copper layers, 70.0 x 12.0 mm, 24 parts (0 on the bottom side), 8 nets.

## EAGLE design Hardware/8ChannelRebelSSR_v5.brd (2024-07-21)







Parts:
3V3: LEDCHIPLED_0805; CHIPLED_0805
5V: 2k; CHIPLED_0805
74LVC2: IC_BUFF_SN74LVC1T45DBV; DBV-R-PDSO-G6
ACOK!: LED0805; CHIPLED_0805
B100: DBS107G; DBS
C1, C5: 0,1uf; 0805-NO
C2, C11: 10uf; 0805-NO
C3, C4, C7: 10uF; 0805-NO
C6, C12: 0,1uf; 0805_NOTHERMALS@1
C8: 10uf; 0805_NOTHERMALS@1
C9: CPOL-EUE1.8-4; E1,8-4
C10: 1uf; 0805-NO
C100: 2,2uf; 0805_NOTHERMALS@1
CONN1: STEMMA_I2C_QT; JST_SH4
D1, D2, D3, D4: WS2812B
IC1: IC_ULN2803ADW; SO-18L
INFRA: 38kHz; TSOP382
J1, J2: CONN_03POLAR; MOLEX-1X3
J3: CONN_02POLAR; MOLEX-1X2
J4: 455-1750-1-ND; 1X03
J5, J6, J7, J8, J9, J10, J11, J12, J13: CONN_023.5MM; SCREWTERMINAL-3.5MM-2
JP1: JUMPER2
JP2: JUMPER-SMT_2_NO_SILK; SMT-JUMPER_2_NO_SILK
JP3: JUMPER-PAD-3-NC_BY_TRACE; PAD-JUMPER-3-3OF3_NC_BY_TRACE_YES_SILK_FULL_BOX
JP100: JUMPER-SMT_3_2-NC_PASTE_SILK; SMT-JUMPER_3_2-NC_PASTE_SILK
K1, K2, K3, K4, K5, K6, K7, K8: AQG12105; AQG
OK100: LTV816S; DIL4-SMD
OK101: TLP283; MINI-FLAT-4
P1, P2, P3, P4, P5, P6, P7, P8: LED0805; CHIPLED_0805
PCB1: PCB_DP_RECTANGLE-80X100; DP10080_V1
R1: 300o; R805
R2: 2k; R805
R3, R11, R109: 10k; 0805@1
R4: 200; 0805@1
R5: proto 4.7k; 0805@1
R6, R7, R8: proto 10k; 0805@1
R9: 33Ohm; R805
R10, R12, R13: 10k; R805
R14: proto 10k proto 68k; 0805@1
R100, R101, R102, R103, R104, R105: 10k proto 51k; 0805@1
R106, R107: proto 2k; 0805@1
R108: proto 330k 390k proto 120k proto 330k 430k; 0805@1
R110: proto 330 kproto 68k; 0805@1
RN100, RN101: RESISTOR_ARRAY_4; RN8P-4R-CRA06S
SW1: CI-11
U1: DS18B20; TO-92-AMMO
U2: SN74LVC1G17DBVR; SOT95P280X145-5N
U$1: MH-ET_ESP32_D1_MINI
U$2: DISPLAY-OLED-128X64-I2CEXTHOLES; DISPLAY-OLED-128X64-MAX-I2C
U$4: SWITCH4.5-4,5; SWITCH4.5X4.5
U$5: 1188
U$6: AP11173V3; SOT223
U$7: ACDC-SUPPLY; ACDC-5V
U$15, U$17: EST026_COLDPRESSTERMINAL; EST026-COLDPRESSTERMINAL
U$16, U$18: SCREWTERMINAL_BLOCL5X5_FLAT; SCREWTERMINALFLAT5X5
X1: STEREOJACK; STX3100

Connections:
3V3: 3V3.A, 74LVC2.1 (VCCA), C2.2, C4.2, C5.2, C11.2, CONN1.2 (V+), INFRA.3 (VS), J2.1, R3.2, R5.2, R6.1, R7.1, R8.1, R10.1, R11.2, R13.1, R14.2, R109.2, RN100.1, RN100.2 (1), RN100.3 (1), RN100.4 (1), RN101.1, RN101.2 (1), RN101.3 (1), RN101.4 (1), U1.3 (VDD), U2.5 (VCC), U$1.3V3, U$2.2 (VCC), U$6.2 (VOUT), U$6.4 (VOUT)
5V: 5V.A, 74LVC2.6 (VCCB), C1.2, C3.2, C7.2, D1.1 (VCC), D2.1 (VCC), D3.1 (VCC), D4.1 (VCC), J1.1, J3.1, J4.3, JP100.3, R100.2, R101.2, R102.2, R103.2, R104.2, R105.2, R106.2, R107.2, U$1.VCC, U$6.3 (VIN)
12V: J4.1, JP100.1, U$7.P$2 (VCC)
+: OK100.1 (A), OK101.1 (A), R108.2, R110.2
-: ACOK!.C, B100.-, OK100.2 (C), OK101.2 (C)
BTN: U$1.TD0 (IO15), U$4.A (1), U$5.P$3 (1)
CURRENT-: C8.1, C9.+, C12.2, R9.2, R10.2, R12.1, X1.4, X1.5; also elsewhere on the board
CURRENTSIGNAL: C12.1, JP3.2, R9.1, U$1.IO34; also elsewhere on the board
DIODE+: B100.+, R108.1
DMX-RTS: U$1.IO5; also elsewhere on the board
DMX-RX: U$1.IO0
DMX-TX: U$1.TMS (IO14); also elsewhere on the board
ENCODERA: R6.2, SW1.A, U$1.TCK (IO13)
ENCODERB: R7.2, SW1.B, U$1.SVP (IO36)
ENCODERS: R8.2, SW1.D, U$1.IO4
GND: 74LVC2.2 (GND), C1.1, C2.1, C3.1, C4.1, C5.1, C6.2, C7.1, C8.2, C9.-, C10.1, C11.1, C100.2, CONN1.1 (GND), D1.3 (GND), D2.3 (GND), D3.3 (GND), D4.3 (GND), IC1.9 (GND), INFRA.2 (GND), J1.3, J2.3, J3.2, J4.2, OK100.3 (EMIT), OK101.3 (EMIT), R1.1, R2.1, R12.2, SW1.C, SW1.E, U1.1 (GND), U2.3 (GND), U$1.GND, U$1.GND2 (GND), U$1.GND3 (GND), U$2.1 (GND), U$4.B (2), U$4.GND (SHIELD), U$5.P$1, U$5.P$2, U$5.P$4 (3), U$6.1 (GND), U$7.P$1 (GND)
INFRASIGNAL: INFRA.1 (OUT), R11.1, U$1.IO35
LINE: B100.AC2, J13.1, K1.O1 (DS2), K2.O1 (DS2), K3.O1 (DS2), K4.O1 (DS2), K5.O1 (DS2), K6.O1 (DS2), K7.O1 (DS2), K8.O1 (DS2), U$7.P$4 (L), U$15.P$1, U$15.P$2, U$16.P$1
unnamed 18: C100.1, JP2.2; also elsewhere on the board
unnamed: 74LVC2.5 (DIR), R3.1
unnamed: 74LVC2.4 (B), R4.1
unnamed: D1.2 (DO), D2.4 (DI)
unnamed: D2.2 (DO), D3.4 (DI)
unnamed: D3.2 (DO), D4.4 (DI)
unnamed: ACOK!.A, R110.1
unnamed: 3V3.C, R1.2
unnamed: 5V.C, R2.2
unnamed: P4.A, R103.1
unnamed: P3.A, R102.1
unnamed: P2.A, R101.1
unnamed: P1.A, R100.1
unnamed: P8.A, R107.1
unnamed: P7.A, R106.1
unnamed: P6.A, R105.1
unnamed: P5.A, R104.1
NEUTRAL: B100.AC1, J5.1, J6.1, J7.1, J8.1, J9.1, J10.1, J11.1, J12.1, J13.2, U$7.P$3 (N), U$17.P$1, U$17.P$2, U$18.P$1
unnamed: JP3.1, X1.2, X1.3
unnamed: JP3.3, X1.1
POTI-DMXRX: J2.2, R13.2, U$1.SVN (IO39); also elsewhere on the board
RGB3V3: 74LVC2.3 (A), U$1.IO32
RGB5V: D1.4 (DI), J1.2, R4.2
SCL: CONN1.4 (SCL), U$1.IO22, U$2.3 (SCL)
SDA: CONN1.3 (SDA), U$1.IO21, U$2.4 (SDA)
SSR1: IC1.18 (O1), K1.- (K), P1.C
SSR1-3V3: IC1.1 (I1), RN100.8 (2), U$1.IO26
SSR2: IC1.17 (O2), K2.- (K), P2.C
SSR2-3V3: IC1.2 (I2), RN100.7 (2), U$1.IO18
SSR3: IC1.16 (O3), K3.- (K), P3.C
SSR3-3V3: IC1.3 (I3), RN100.6 (2), U$1.IO19
SSR4: IC1.15 (O4), K4.- (K), P4.C
SSR4-3V3: IC1.4 (I4), RN100.5 (2), U$1.IO23
SSR5: IC1.14 (O5), K5.- (K), P5.C
SSR5-3V3: IC1.5 (I5), RN101.8 (2), U$1.IO17
SSR6: IC1.13 (O6), K6.- (K), P6.C
SSR6-3V3: IC1.6 (I6), RN101.7 (2), U$1.IO16
SSR7: IC1.12 (O7), K7.- (K), P7.C
SSR7-3V3: IC1.7 (I7), RN101.6 (2), U$1.IO27
SSR8: IC1.11 (O8), K8.- (K), P8.C
SSR8-3V3: IC1.8 (I8), RN101.5 (2), U$1.IO25
SSROUT-1: J5.2, K1.O2 (DS1)
SSROUT-2: J6.2, K2.O2 (DS1)
SSROUT-3: J7.2, K3.O2 (DS1)
SSROUT-4: J8.2, K4.O2 (DS1)
SSROUT-5: J9.2, K5.O2 (DS1)
SSROUT-6: J10.2, K6.O2 (DS1)
SSROUT-7: J11.2, K7.O2 (DS1)
SSROUT-8: J12.2, K8.O2 (DS1)
TEMP: JP1.2, U$1.IO2
TEMP-JP: JP1.1, R5.1, U1.2 (DQ)
VSSR: C6.1, C10.2, IC1.10 (CD+), JP100.2, K1.+ (A), K2.+ (A), K3.+ (A), K4.+ (A), K5.+ (A), K6.+ (A), K7.+ (A), K8.+ (A)
ZEROSIGNAL: R14.1, U2.4 (Y), U$1.IO33
ZEROSIGNALRAW: JP2.1, OK100.4 (COL), OK101.4 (COL), R109.1, U2.2 (A); also elsewhere on the board

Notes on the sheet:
Sleeve
Ring1
Tip
Ring2
https://www.casler.org/wordpress/low-current-measurement-performance-of-the-sct013/
Ring



Board: 2 copper layers, 100.0 x 80.0 mm, 111 parts (23 on the bottom side), 69 nets.

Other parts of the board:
J14: AUDIO_JACK_TRRSSMD_RA; AUDIO_JACK_3.5MM_TRRS_SMD_RA
J15: JST_6_PIN_VERTICAL; JST-6-SMD-VERT-1.0MM
J16: BM06B-SRSS-TB; JST-6-SMD-HORI-1.0MM
JP101: JUMPER-SMT_2_NO_SILK; SMT-JUMPER_2_NO_SILK
U$3: LOGOONONOLU_3MM_TOP
U$8, U$9, U$10, U$11, U$12, U$13, U$14: SPARKLOGO
U$19: W32-ETH01; WT32-ETH01-DIM

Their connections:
CURRENT-: J14.TIP; also elsewhere on the board
CURRENTSIGNAL: J14.EARTH, J14.RING2; also elsewhere on the board
DMX-RTS: J15.5; also elsewhere on the board
DMX-TX: J15.4; also elsewhere on the board
unnamed 18: JP101.2; also elsewhere on the board
POTI-DMXRX: J15.3; also elsewhere on the board
ZEROSIGNALRAW: JP101.1; also elsewhere on the board

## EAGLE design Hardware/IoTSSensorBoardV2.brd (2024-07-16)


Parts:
1, 2, 3: JUMPER-SMT_2_NO_SILK; SMT-JUMPER_2_NO_SILK
C1, C2: 10uF; 0805-NO
CONN1: STEMMA_I2C_QT; JST_SH4
JOS: JUMPER-SMT_2_NO_SILK; SMT-JUMPER_2_NO_SILK
JP4: JSTSH2PIN; SM02B-SRSS-TB
Q1: 500mA/300V; SOT23-3
R1, R2: RESISTORR805-0805; R805
RN1: RESISTOR_ARRAY_4; RN8P-4R-CRA06S
TEMP1: RED; CHIPLED_0805
U1: TEMP_LM75B; TSSOP8
U$12: BOARD32X12; OVAL3212MM

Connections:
unnamed: R1.2, TEMP1.C
T3V3: 1.1, 2.1, 3.1, C2.1, CONN1.2 (V+), R2.2, TEMP1.A, U1.8 (VCC)
TDN: C1.2, JP4.2, Q1.1 (B), Q1.2 (E)
TDP: C1.1, JOS.2, JP4.1, Q1.3 (C), R2.1
TGND: C2.2, CONN1.1 (GND), CONN1.MT1 (MT), CONN1.MT2 (MT), RN1.1, RN1.2 (1), RN1.3 (1), U1.4 (GND)
TOS: JOS.1, R1.1, U1.3 (OS)
TSCL: CONN1.4 (SCL), U1.2 (SCL)
TSDA: CONN1.3 (SDA), U1.1 (SDA)
TTA0: 1.2, RN1.6 (2), U1.7 (A0)
TTA1: 2.2, RN1.7 (2), U1.6 (A1)
TTA2: 3.2, RN1.8 (2), U1.5 (A2)


Board: 2 copper layers, 32.0 x 12.0 mm, 15 parts (0 on the bottom side), 11 nets.

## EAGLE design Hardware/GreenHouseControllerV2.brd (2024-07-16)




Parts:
3V3OK, 5VOK: RED; CHIPLED_0805
74LVC1: IC_BUFF_SN74LVC1T45DBV; DBV-R-PDSO-G6
$$U$1: TESTHOOK
BUTTON: KMR2; BTN_KMR2_4.6X2.8
C1, C3, C13: CAPACITOR_NPOL-0805; C805
C2: C-USC1210; C1210
C4, C7: 10uf; C805
C9: 100uf; C1210
C11, C12: 4,7uf; C805
C14: 4,7uF; 0805-NO
CN1: RESISTOR_ARRAY_4; RN8P-4R-CRA06S
CONN1, CONN2: STEMMA_I2C_QT; JST_SH4
IC1: LTC4311_SC70; SC70-6L
IO0, IO14, IO15, IO25, IO27, IO32, IO33: JUMPER-SMT_3_2-NC_PASTE_SILK; SMT-JUMPER_3_2-NC_PASTE_SILK
J1: CONN_03POLAR; MOLEX-1X3
J2, J3, J5: CONN_02POLAR; MOLEX-1X2
J4: CONN_03SCREW; SCREWTERMINAL-3.5MM-3
J6, J10: CONN_023.5MM; SCREWTERMINAL-3.5MM-2
J7, J8: 282834-2; CONN_282834-2
J9: CONN_06NO_SILK_FEMALE_PTH; 1X06_NO_SILK
J11: CONN_04; 1X04
J12: CONN_04JST-PH-4-1.0MM; JST-4-SMD-VERT-1.0MM
J16: CONN_04POLAR; MOLEX-1X4
JP1, JP2, JP3, JP4, JP5, JP6, JP7, JP8, JP9, JP10, JP11, JP12, JP13, JP14: JUMPER-SMT_2_NC_PASTE_SILK; SMT-JUMPER_2_NC_PASTE_SILK
JP100: JSTSH6PIN; SM06B-SRSS-TB
K1: FPC4PIN_1MM_MAX; FPC_CONN_DOC_4PIN_ENLARGED
LEVEL1-IO39, LEVEL2-IO35, LEVEL3-IO34, LEVEL4-IO36: JST-XH-04-PIN-ROUND-PAD; JST-XH-04-PACKAGE-ROUND-PAD
PCB1: PCB_DP_RECTANGLE-50X100; DP10050_V1
Q5: VNN7NV04; SOT223
R1, R2, R3, R26: 1k; R805
R4, R5, R8, R9, R10, R11, R12, R13, R14, R16, R18, R19, R20, R23, R24: 10k; R805
R6, R21, R22: RESISTORR805-0805; R805
R7: 330; R805
R15, R25: 10K; R805
R17: 4,7k; R805
R27: 2k; R805
RGB: JUMPER-SMT_3_2-NC_PASTE_SILK; SMT-JUMPER_3_2-NC_PASTE_SILK
RN1, RN3: RESISTOR_ARRAY_4; RN8P-4R-CRA06S
RN2: 4,3k; RN8P-4R-CRA06S
RN4: 330; RN8P-4R-CRA06S
S1, S2, S3, S4: LED-0805; LED-805
SERVO1, SERVO2, SERVO3, SERVO4: CONN_03POLAR; MOLEX-1X3
STATUS: RED; CHIPLED_0805
U1: SN74LVC07ADR; SOIC127P600X175-14N
U$1: LOGOTOPTERRA
U$3: MH-ET_ESP32_D1_MINI
U$4, U$5, U$6, U$9, U$10: TESTHOOK
U$7: V_REG_LD1117VXXLD1117-SMD; SOT223
U$8: USB_PD_TRIGGER; USB-PDTRIGGER
ULN1: ULN2803SOICW; SO18L
X5, X7: JST-XH-03-PIN-ROUND-PAD; JST-XH-03-PACKAGE-ROUND-PAD
X6: JST-XH-02-PIN-ROUND-PAD; JST-XH-02-PACKAGE-ROUND-PAD
X8: JST-XH-05-PIN-ROUND-PAD; JST-XH-05-PACKAGE-ROUND-PAD

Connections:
1-WIRE: R17.1, U$3.IO17, X5.3
1Y: U1.2 (1Y)
3V3: 3V3OK.A, 74LVC1.1 (VCCA), BUTTON.B (S), BUTTON.B' (S1), C1.1, C7.1, C12.1, C14.1, CONN1.2 (V+), CONN2.2 (V+), IC1.1 (VCC), J5.2, J9.6, J12.3, JP13.2, K1.4, LEVEL1-IO39.1, LEVEL2-IO35.1, LEVEL3-IO34.1, LEVEL4-IO36.1, R5.1, R6.1, R8.2, R9.2, R10.2, R11.2, R12.2, R13.2, R14.2, R16.2, R17.2, R18.2, R19.2, R20.2, R21.1, R22.1, R23.2, R24.2, R25.1, RN1.5 (2), RN1.6 (2), RN1.7 (2), RN1.8 (2), RN4.1, RN4.2 (1), RN4.3 (1), RN4.4 (1), STATUS.A, U$3.3V3, U$7.2 (OUT), X5.1, X6.2, X7.3
5V: 5VOK.A, 74LVC1.6 (VCCB), $$U$1.P$1, C2.1, C3.2, C4.1, C11.1, J2.2, J11.1, J16.1, JP2.2, JP5.2, JP6.2, JP8.2, JP9.2, JP12.2, JP100.2, RN3.5 (2), RN3.6 (2), RN3.7 (2), RN3.8 (2), U1.14 (VCC), U$3.VCC, U$7.3 (IN)
ANODEA0: LEVEL1-IO39.2, RN4.5 (2)
ANODEA1: LEVEL2-IO35.2, RN4.6 (2)
ANODEA2: LEVEL4-IO36.2, RN4.7 (2)
ANODEA3: LEVEL3-IO34.2, RN4.8 (2)
BTN1: BUTTON.A, BUTTON.A' (P1), R15.1, U$3.TDI (IO12)
CS: J9.1
EN: IC1.3 (EN), R25.2
FANCOUNTER: IO0.1, IO32.1, J1.3
FANGND: J1.1, Q5.2 (D), Q5.4 (D2)
FANPWM: Q5.1 (G), R14.1, U$3.IO16
GND: 74LVC1.2 (GND), C1.2, C2.2, C3.1, C4.2, C7.2, C9.2, C11.2, C12.2, C13.1, C14.2, CN1.3 (1), CN1.4 (1), CN1.7 (2), CN1.8 (2), CONN1.1 (GND), CONN1.MT1 (MT), CONN1.MT2 (MT), CONN2.1 (GND), CONN2.MT1 (MT), CONN2.MT2 (MT), IC1.2 (GND), IC1.5 (GND), J2.1, J3.1, J4.1, J5.1, J6.2, J7.2, J8.2, J9.5, J10.2, J11.2, J11.3, J12.4, J16.4, JP14.2, JP100.1, K1.3, LEVEL1-IO39.4, LEVEL2-IO35.4, LEVEL3-IO34.4, LEVEL4-IO36.4, Q5.3 (S), R1.2, R2.2, R4.1, R15.2, R27.2, RN2.1, RN2.2 (1), RN2.3 (1), RN2.4 (1), SERVO1.1, SERVO2.1, SERVO3.1, SERVO4.1, U1.7 (GND), U$3.GND, U$3.GND2 (GND), U$3.GND3 (GND), U$5.P$1, U$6.P$1, U$7.1 (GND), U$8.P$1 (GND), U$8.P$2 (GND), U$9.P$1, ULN1.9, X5.2, X7.1
IO0: IO0.2, R10.1, U$3.IO0
IO4: R12.1, RGB.3, U$3.IO4
IO14: IO14.2, R11.1, U$3.TMS (IO14)
IO15: IO15.2, R8.1, U$3.TD0 (IO15)
IO25: IO25.2, R23.1, U$3.IO25
IO27: IO27.2, R24.1, U$3.IO27
IO32: IO32.2, R19.1, U$3.IO32
IO33: IO33.2, R20.1, U$3.IO33
LED: R3.1, U$3.IO2
LEDVCC: J4.3, JP3.1, JP8.1
LEVEL1: CN1.5 (2), LEVEL1-IO39.3, RN2.5 (2), U$3.SVN (IO39)
LEVEL2: CN1.6 (2), LEVEL2-IO35.3, RN2.6 (2), U$3.IO35
LEVEL3: CN1.2 (1), LEVEL4-IO36.3, RN2.7 (2), U$3.IO34
LEVEL4-SONARECHO: CN1.1, JP7.1, LEVEL3-IO34.3, R26.2, R27.1, U$3.SVP (IO36)
LIMIT1: IO14.3, IO25.3, J7.1
LIMIT2: IO32.3, IO33.3, J8.1
MOSFETVCC1: JP4.1, JP5.1, SERVO1.2, SERVO2.2
MOSFETVCC2: J1.2, JP1.1, JP2.1
unnamed: 5VOK.C, R2.1
unnamed: R3.2, STATUS.C
unnamed: JP7.2, RN2.8 (2)
unnamed: 3V3OK.C, R1.1
unnamed: RN3.4 (1), S1.A
unnamed: RN3.3 (1), S2.A
unnamed: RN3.2 (1), S3.A
unnamed: RN3.1, S4.A
unnamed: 74LVC1.5 (DIR), R6.2
unnamed: 74LVC1.4 (B), R7.2
PIO1: R18.1, U1.13 (6A), U$3.IO19
PIO2: R16.1, U1.11 (5A), U$3.IO23
PIO3: R13.1, U1.9 (4A), U$3.IO5
PIO4: R9.1, RGB.1, U1.5 (3A), U$3.TCK (IO13)
PIO5V-1: JP100.3, U1.12 (6Y)
PIO5V-2: JP100.4, U1.10 (5Y)
PIO5V-3: JP100.5, SERVO2.3, U1.8 (4Y)
PIO5V-4: JP100.6, SERVO1.3, U1.6 (3Y)
RGB3V3: 74LVC1.3 (A), RGB.2
RGB5V: J4.2, R7.1
RST: U$3.RST
SCL: CONN1.4 (SCL), CONN2.4 (SCL), IC1.6 (BUS1), J9.4, J12.1, K1.2, R22.2, U$3.IO22
SD0: J9.2, JP14.1
SDA: CONN1.3 (SDA), CONN2.3 (SDA), IC1.4 (BUS2), J9.3, J12.2, K1.1, R21.2, U$3.IO21
SERVO1-TRIGGER: IO14.1, IO27.3, J16.2, SERVO4.3
SERVO2: IO15.3, IO33.1, SERVO3.3
SERVOVCC: JP11.1, JP12.1, JP13.1, SERVO3.2, SERVO4.2
SONAR: J16.3, R26.1
STEPPER1: S1.C, ULN1.17, ULN1.18, X8.2
STEPPER2: S2.C, ULN1.15, ULN1.16, X8.3
STEPPER3: S3.C, ULN1.13, ULN1.14, X8.4
STEPPER4: S4.C, ULN1.11, ULN1.12, X8.5
STEPPERA: IO27.1, RN1.4 (1), ULN1.1, ULN1.2
STEPPERB: IO25.1, RN1.3 (1), ULN1.3, ULN1.4
STEPPERC: IO0.3, RN1.2 (1), ULN1.5, ULN1.6
STEPPERD: IO15.1, RN1.1, ULN1.7, ULN1.8
STEPPERVCC: JP9.1, JP10.1, ULN1.10, X8.1
TURBINETACH: R5.2, U$3.IO18, X7.2
TURBINETHERM: R4.2, U$3.IO26, X6.1
VIN1: C9.1, C13.2, J6.1, J10.1, J11.4, JP4.2, JP6.1, JP10.2, JP11.2, U$8.P$3 (VUSBPD), U$8.P$4 (VUSBPD), U$10.P$1
VIN2: J3.2, JP1.2, JP3.2, U$4.P$1

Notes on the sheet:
PCA9685 found at 0x40 LM75AD found at 0x4b ADS1210C : GND GND 0x55
Blue-Anode
Red-gnd
White-Vdd
Yellow-A0
Prototype:4,3K
proto1 330
VP-GPIO36 VN-GPIO39 RTC4-GPIO34 RTC5-GPIO35 UART 0 TX : GPIO1 UART 0 RX : GPIO3 SDA : GPIO21 SCL : GPIO22 GPIO 6-11 : ONLY SPI STRAPPING PINS: GPIO 0 PWM AT BOOT - PULLED UP GPIO 1 DEBUG AT BOOT - ONLY TX (NO PERFECT) GPIO 2 TO LED GIPO 3 HIGH AT BOOT - ONLY RX (NO PERFECT) GPIO 5 HIGH - PWM AT BOO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
SD1 : GPIO8
CLK : GPIO6
SD0 : GPIO7
TDO : GPIO15
WLED ESP32 based boards use IO16 or G16
TDI : GPIO12
Terra
Helios
Mosfet
Turbine
ADC 3PIN
JST 3PIN
FAN PWM - Mosfet
FAN COUNTER/Alt. Limit
Level Input
RGB Output
Stepper Output
I2C
POWER Connector
Servo - Mosfet
FAN In-Output
Limit Switch
Servo Switch
1-Wire
ESP32 has 6 strapping pins: • MTDI/GPIO12: internal pull-down • GPIO0: internal pull-up • GPIO2: internal pull-down • GPIO4: internal pull-down • MTDO/GPIO15: internal pull-up • GPIO5: internal pull-up
Serial Master<>Slave
PIO1:19 PIO2:IO23 PIO3:05
PIO1:IO19 PIO2:IO23 PIO3:IO05 PIO4:IO13



Board: 2 copper layers, 100.0 x 50.0 mm, 118 parts (59 on the bottom side), 71 nets.

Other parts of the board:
U$2: LOGOGREENHOUSE

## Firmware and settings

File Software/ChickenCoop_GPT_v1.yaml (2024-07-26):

# Designed with ChatGPT not tested, not a single line written.

esphome:
  name: chicken_coop
  platform: ESP8266
  board: nodemcuv2

wifi:
  ssid: "YOUR_SSID"
  password: "YOUR_PASSWORD"

# Enable logging
logger:

# Enable Home Assistant API
api:

ota:

i2c:
  sda: D2
  scl: D1
  scan: True

sensor:
  - platform: tsl2561
    name: "TSL2561 Ambient Light"
    address: 0x39
    update_interval: 60s
    id: tsl_sensor
    on_value_range:
      - above: !lambda 'return id(lux_threshold_sunrise).state;'
        then:
          - cover.open: garage_door
          - lambda: |-
              ESP_LOGD("Custom", "Lux above threshold, opening door.");
      - below: !lambda 'return id(lux_threshold_sunset).state;'
        then:
          - cover.close: garage_door
          - lambda: |-
              ESP_LOGD("Custom", "Lux below threshold, closing door.");

time:
  - platform: sntp
    id: sntp_time
    timezone: "YOUR_TIMEZONE" # Replace with your timezone
    latitude: YOUR_LATITUDE  # Replace with your latitude
    longitude: YOUR_LONGITUDE  # Replace with your longitude
    on_time:
      - seconds: 0
        minutes: 0
        then:
          - lambda: |-
              ESP_LOGD("Custom", "Synchronizing NTP time to RTC.");
              if (id(sntp_time).now().is_valid()) {
                id(rtc_time).set_time(id(sntp_time).now());
              }

  - platform: ds3231
    id: rtc_time
    timezone: "YOUR_TIMEZONE" # Replace with your timezone
    on_time:
      - seconds: 0
        minutes: /45  # Check every 45 minutes
        then:
          - lambda: |-
              ESP_LOGD("Custom", "Checking door operations based on time and lux values.");
              auto time = id(rtc_time).now();
              if (time.is_valid()) {
                auto sunrise = id(rtc_time).sunrise();
                auto sunset = id(rtc_time).sunset();
                float lux = id(tsl_sensor).state;
                if (lux > id(lux_threshold_sunrise).state && time.is_after(sunrise, 0)) {
                  id(garage_door).open();
                } else if (lux < id(lux_threshold_sunset).state && time.is_after(sunset, 0)) {
                  id(garage_door).close();
                }
              } else {
                ESP_LOGE("Custom", "Invalid time data, please check RTC settings.");
              }

cover:
  - platform: template
    name: "Chicken Coop Door"
    id: garage_door
    open_action:
      - stepper.set_target:
          id: stepper
          target: 0  # Open the door (target position for open)
    close_action:
      - stepper.set_target:
          id: stepper
          target: !lambda 'return id(calibration_position_down).state;'  # Close the door (target position for closed)
    stop_action:
      - stepper.set_target:
          id: stepper
          target: id(stepper).current_position  # Stop the motor
    optimistic: true

output:
  - platform: gpio
    pin: D1
    id: stepper_step
  - platform: gpio
    pin: D2
    id: stepper_dir

# Stepper motor configuration for 28BYJ-48
stepper:
  - platform: uln2003
    id: stepper
    step_pin: D1
    dir_pin: D2
    max_speed: 250 steps/s
    sleep_pin: D3
    acceleration: inf
    deceleration: inf

binary_sensor:
  - platform: gpio
    pin: D5
    name: "Top Endstop"
    id: top_endstop
    on_press:
      then:
        - cover.open: garage_door  # Mark door as open when top endstop is hit
        - stepper.report_position:
            id: stepper
            position: 0
        - stepper.set_target:
            id: stepper
            target: 0  # Stop the stepper motor when top endstop is hit

  - platform: gpio
    pin: D6
    name: "Bottom Endstop"
    id: bottom_endstop
    on_press:
      then:
        - cover.close: garage_door  # Mark door as closed when bottom endstop is hit
        - stepper.report_position:
            id: stepper
            position: !lambda 'return id(calibration_position_down).state;'
        - stepper.set_target:
            id: stepper
            target: !lambda 'return id(calibration_position_down).state;'  # Stop the stepper motor when bottom endstop is hit

  - platform: gpio
    pin: D7
    name: "Manual Open Button"
    id: manual_open_button
    on_press:
      then:
        - cover.toggle: garage_door  # Toggle door state when button is pressed

switch:
  - platform: gpio
    name: "Calibration Mode"
    pin: D8
    id: calibration_switch
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

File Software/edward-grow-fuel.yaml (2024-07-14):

esphome:
  name: edward-grow-fuel
  friendly_name: edward-grow-fuel
  on_boot:
    priority: -10
    then:
      - switch.turn_on: automationLoop
      - delay: 5s
      - if:
          condition:
            - time.has_time
            - lambda: |-
                int current_time = id(sntpTime).now().hour * 60 + id(sntpTime).now().minute;
                int sun_light_on_time = (int) id(plantSunLightOnTime).state;
                int sun_light_off_time = (int) id(plantSunLightOffTime).state;
                return current_time >= sun_light_on_time && current_time < sun_light_off_time;
          then:
            - switch.turn_on: helios
          else:
            - switch.turn_off: helios

esp32:
  board: esp32dev
  framework:
    type: arduino

# Enable logging
logger:

# Enable Home Assistant API
api:
  encryption:
    key: "7e6bVIb1AuGddrYbL3CSajzO3r0g/Vnul5seGnVluxs="

ota:
  password: "af18343b8868e5b71be64650f48d4952"

wifi:
  ssid: !secret wifi_ssid
  password: !secret wifi_password

  # Enable fallback hotspot (captive portal) in case wifi connection fails
  ap:
    ssid: "Edward-Test-Alex"
    password: "PzNNYylJ6Hbl"

captive_portal:

# --- [ WebServer ] ---
web_server:
  port: 80
  local: true

# --- [ Local variables ] ---
globals:
  - id: 'timer' # used to calculate the time needed to fill or empty the plant tank
    type: int
    restore_value: false

# --- [ Global variables ] ---
number:
  # Water cycle
  - platform: template
    id: 'plantLowTideTime'
    name: "Plants - Low tide time"
    unit_of_measurement: "min"
    icon: mdi:timeline-clock-outline
    initial_value: 10
    max_value: 1440  # 24h
    min_value: 1
    step: 1
    mode: box
    optimistic: true
    restore_value: true

  - platform: template
    id: 'plantHighTideTime'
    name: "Plants - High tide time"
    unit_of_measurement: "min"
    icon: mdi:timeline-clock-outline
    initial_value: 5
    max_value: 60   # 1h
    min_value: 1
    step: 1
    mode: box
    optimistic: true
    restore_value: true

  # Light control
  - platform: template
    id: 'plantSunLightOnTime'
    name: "Plants - Sun Light On time"
    unit_of_measurement: "hour"
    icon: mdi:timeline-clock-outline
    initial_value: 660  # 11:00
    max_value: 1425     # 23:45
    min_value: 0        # 00:00
    step: 1
    mode: box
    optimistic: true
    restore_value: true

  - platform: template
    id: 'plantSunLightOffTime'
    name: "Plants - Sun Light Off time"
    unit_of_measurement: "hour"
    icon: mdi:timeline-clock-outline
    initial_value: 960  # 16:00
    max_value: 1425     # 23:45
    min_value: 0        # 00:00
    step: 1
    mode: box
    optimistic: true
    restore_value: true
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

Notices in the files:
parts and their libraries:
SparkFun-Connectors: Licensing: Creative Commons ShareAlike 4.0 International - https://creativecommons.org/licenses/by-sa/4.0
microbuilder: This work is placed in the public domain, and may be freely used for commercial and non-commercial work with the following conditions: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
